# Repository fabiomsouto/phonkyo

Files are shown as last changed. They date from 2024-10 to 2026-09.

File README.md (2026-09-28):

# Phonkyo

A PiHat for Onkyo RI-enabled devices, hence the name (PiHat Onkyo).

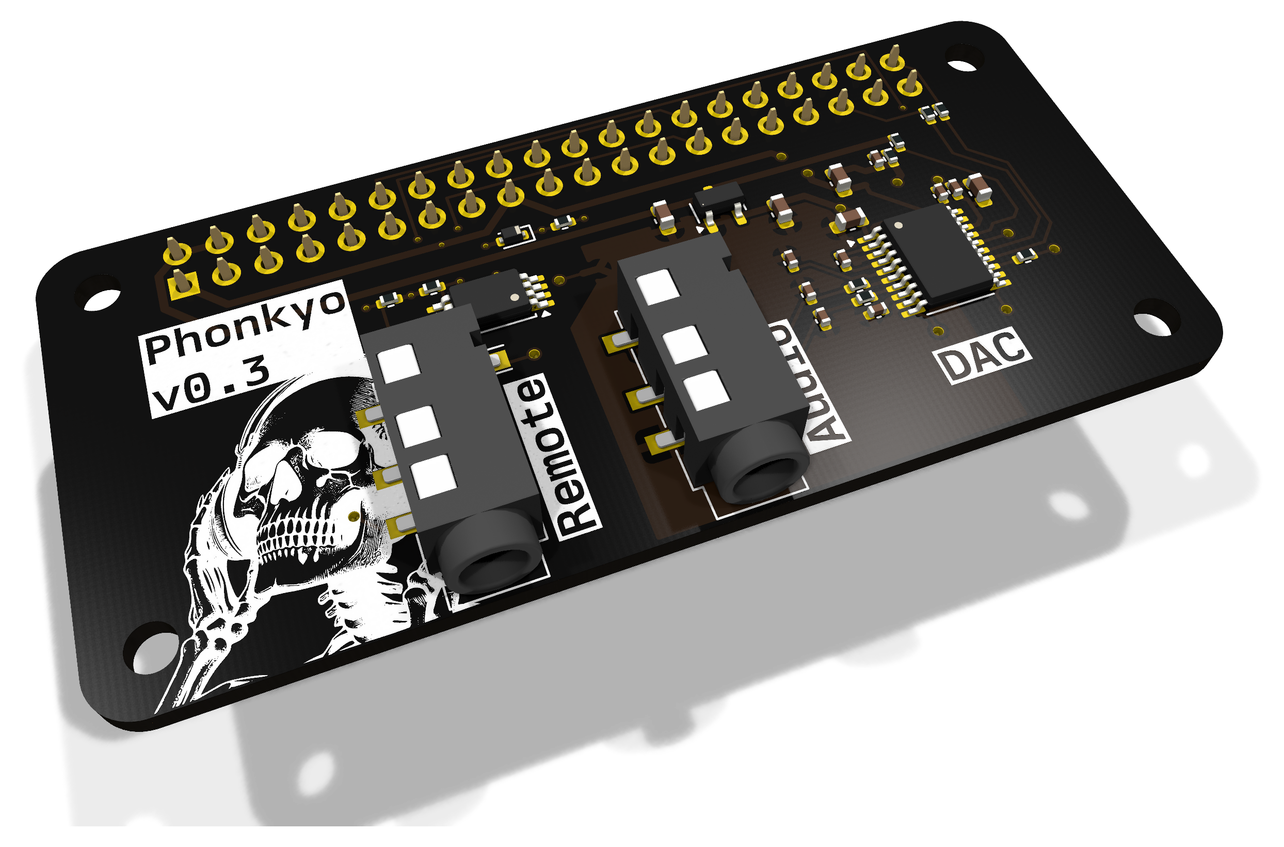
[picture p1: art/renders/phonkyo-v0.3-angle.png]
Phonkyo v0.3


Phonkyo makes a Raspberry Pi behave like one of Onkyo's own docks. Onkyo receivers have a small RI (Remote
Interactive) jack on the back, which docks use to switch the receiver on and change it to the dock input. Phonkyo speaks
the same protocol, so when you start playing music the receiver comes on and selects DOCK by itself, and after a few
minutes of silence it switches off again.

The music comes from the Pi itself: a PCM5102A DAC on the hat turns it into an AirPlay 2 receiver, a Spotify Connect
device and a headless Plexamp player, feeding the receiver's dock input through a line-level output.

I believe this device could also be used for other RI-enabled devices, such as Marantz, but I have no way to test it
(and therefore implement support)!

## What it does

- **Follows playback.** When something starts playing, the receiver powers on and switches to its DOCK input. When
  playback stops, it switches off again, but only if phonkyo was the one that turned it on.
- **High-quality line output.** PCM5102A DAC, 24-bit/192 kHz, on a 3.5 mm line-out jack meant for an amplifier's
  line input.
- **Onkyo RI control.** A second 3.5 mm jack connects to the receiver's RI port. It sends commands and listens to the
  codes the receiver sends back.
- **The receiver's remote controls Plexamp.** Play/pause, next, previous, fast-forward, rewind and repeat on the
  receiver's own remote work on Plexamp, just as they would on an Onkyo dock. AirPlay and Spotify can't be controlled
  this way; see `install/MANIFEST.md`.
- **Plug-and-play (v0.3).** A HAT ID EEPROM lets the Raspberry Pi recognise the board and load the sound card by itself,
  so there is nothing to add to `config.txt`.

Tested with an Onkyo TX-8020 and a Raspberry Pi Zero 2 W. Selecting the TV input and changing the volume are not
possible over RI on the TX-8020; `install/MANIFEST.md` records the full code search.

## Hardware

| | |
|---|---|
| Form factor | pHAT, 65 x 30 mm, for the Raspberry Pi Zero 2 W (fits any 40-pin Pi) |
| DAC | TI PCM5102A over I2S, own 3.3 V analog regulator |
| Outputs | 3.5 mm line out (J2), 3.5 mm Onkyo RI (J4) |
| RI line | GPIO25, with a series resistor and ESD clamp from v0.3 |
| ID EEPROM | CAT24C256 on ID_SD/ID_SC, write protect by solder jumper (v0.3) |

| Top | Bottom |
|---|---|
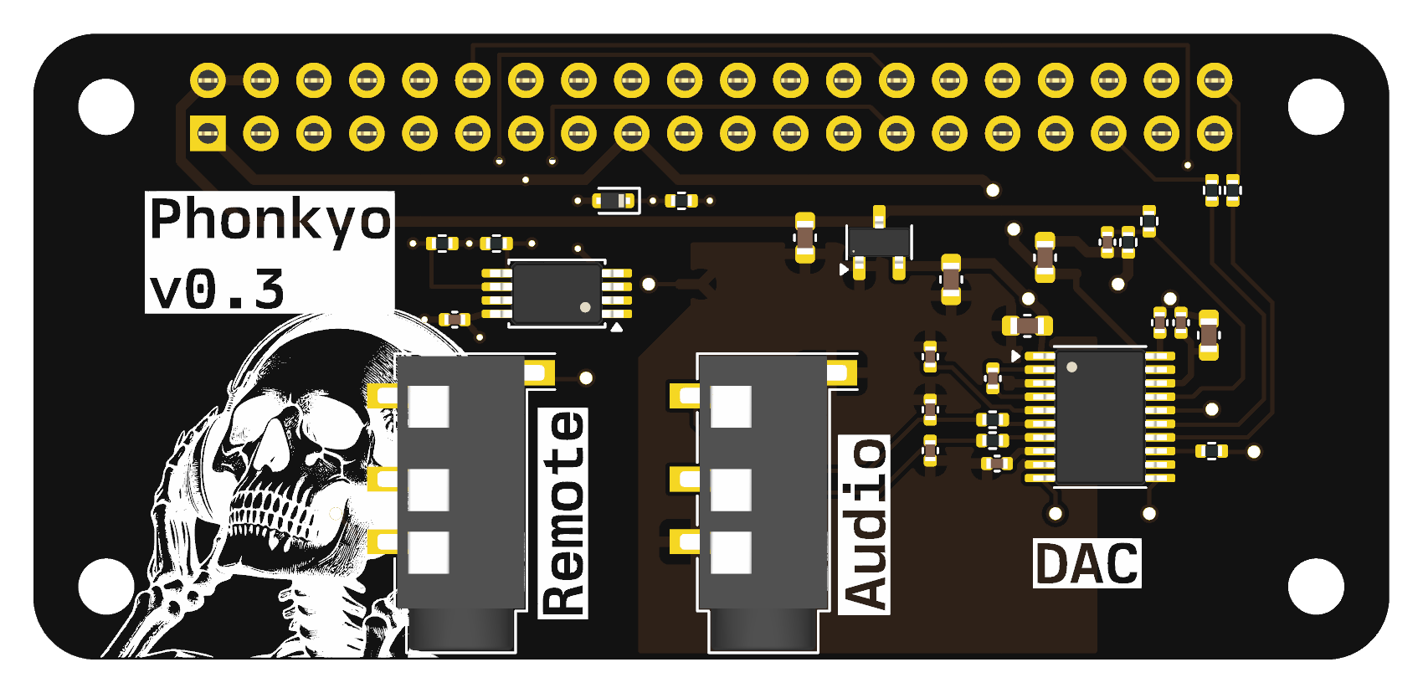
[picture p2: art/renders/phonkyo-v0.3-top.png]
Top
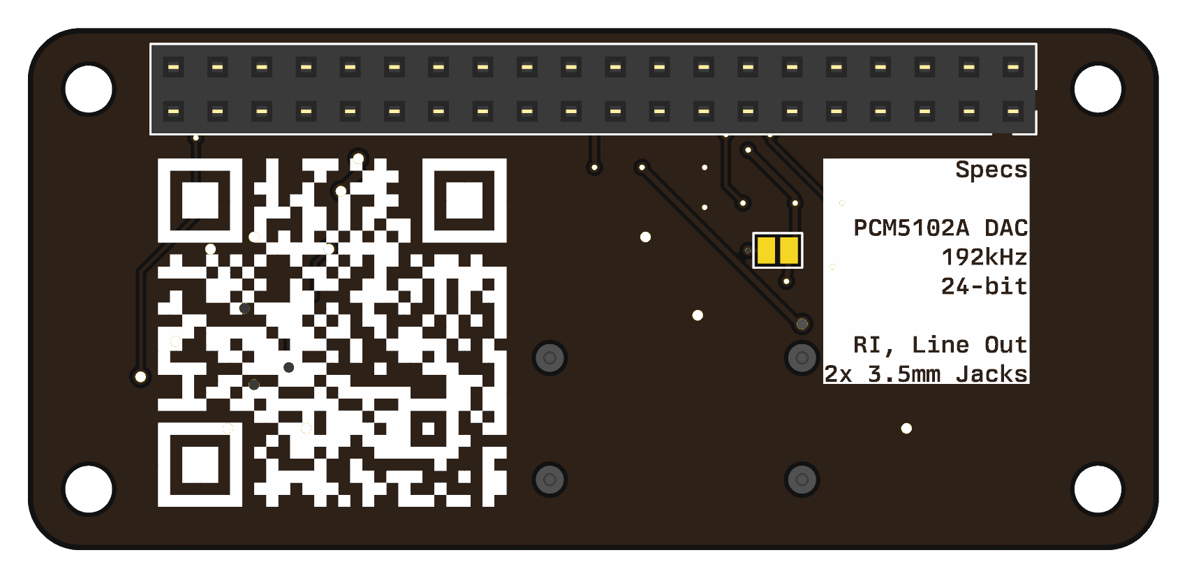
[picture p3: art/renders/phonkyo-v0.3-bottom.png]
Bottom
|  |  |

The design is in KiCad 10: `phonkyo.kicad_sch` and `phonkyo.kicad_pcb`. **v0.2 is the latest revision that has been built
and tested; v0.3 is designed but not yet built.**

## Buying one

Phonkyo is sold in small, hand-built batches through [obcecado.com/phonkyo](https://obcecado.com/phonkyo/).

- **Basic kit:** an assembled Phonkyo board with the 40-pin header already soldered. €30 plus shipping at the time
  of writing; the product page has the current price.
- **Complete kit:** also includes an audio cable, an RI cable and a 3D-printed case. Not available yet.
- **Shipping** is to European Union countries only.

To order, email [phonkyo@obcecado.com](mailto:phonkyo@obcecado.com?subject=Phonkyo%20order) with:

- the kit you want and how many
- the country it ships to
- your receiver model

I'll reply with the total including shipping and how to pay. There's no online checkout.

RI support varies from receiver to receiver, so check the
[compatibility table](https://obcecado.com/phonkyo/#receiver-compatibility) before ordering. Only the Onkyo TX-8020 has
been tested so far. If yours isn't listed, mention it in your email and I'll tell you what I know.

## Getting started

The software runs on Raspberry Pi OS Lite 64-bit (Trixie) on a Raspberry Pi Zero 2 W. On a fresh install, connect to
the Pi over SSH and run:

```sh
curl -fsSL https://obcecado.com/phonkyo/install.sh | bash
```

It asks which players you want and what to call the device, installs everything, and reboots when it's done. It takes
about 10-15 minutes. Plexamp needs a one-time sign-in code from [plex.tv/claim](https://plex.tv/claim), which it asks
for at the right moment. Running it again is safe, and is how you update. The script is `install/phonkyo-setup.sh`.

The [setup guide](https://obcecado.com/phonkyo/setup/) covers flashing the microSD card and the steps by hand, and
`install/MANIFEST.md` is the full technical record of what gets installed and why:

- the DAC and the ALSA setup
- AirPlay 2 (shairport-sync), Spotify Connect (raspotify) and Plexamp
- the RI control code in `software/phonkyo/` and the `phonkyo-monitor` service that follows playback

## Making boards

`production/v0.3/` has everything needed to order assembled boards from JLCPCB: Gerbers, drill files, and a BOM and
placement file with LCSC part numbers. Its README covers the order settings, the parts, and a bring-up checklist for new
boards. The 40-pin header is soldered by hand, and the ID EEPROM is programmed with `make flash` in `hardware/eeprom/`.

`docs/hardware-review-v0.3.md` is a design review of v0.3: what was found, and what was changed.

## Repository layout

| Path | Contents |
|---|---|
| `phonkyo.kicad_*` | KiCad 10 schematic, PCB and project |
| `production/` | Fabrication files for each revision |
| `hardware/eeprom/` | HAT ID EEPROM image source, device tree overlay, build and flash |
| `software/` | RI control, playback monitor, RI sniffer, board detection, systemd unit |
| `install/MANIFEST.md` | Software setup, measured RI timing and verified RI codes |
| `docs/` | Hardware review |
| `art/` | Board artwork and product renders |
| `3dmodels/` | 3D models missing from the KiCad library |
| `adc/` | PCM5102A datasheet |

## Release notes

### v0.1

Initial release of the Phonkyo project. There is no ID EEPROM present yet, and all the hat exposes is a 3.5mm jack that's
connected to the GPIO pin 25 on the Raspberry Pi. Use a mono or a stereo male-to-male cable to connect your Onkyo remote control to the hat.

### v0.2

This release adds the much acclaimed PCM5102A DAC to the design, allowing to expand the functionality of the device beyond a simple
remote control for your home theater system with RI. Depending on your needs, you will now be able to:
- Control your remote interface home theater to your liking
- Expose the Raspberry Pi as a Spotify device
- Expose the Raspberry Pi as an Airplay device
- Expose the Raspberry Pi as a Plex headless player

### v0.3

This release improves on the board design, particularly around power and ground rails, and removes the SCK jumper, as I don't
predict the need for an external clock source in this particular design. It also:
- Fits the HAT ID EEPROM, so the Raspberry Pi sets the board up by itself
- Adds ESD protection and a series resistor on the RI jack
- Moves the DAC's decoupling capacitors next to its pins, and adds one on the analog supply
- Moves the I2S bit clock onto the top layer, over an unbroken ground plane

## Related projects and documentation

[Macsbug article on PCM5102A](https://macsbug-wordpress-com.translate.goog/2021/02/19/web-radio-of-m5stack-pcm5102a-i2s-dac/)

[TI PCM5102A](https://www.ti.com/lit/ds/symlink/pcm5102a.pdf)

[phatDAC](https://shop.pimoroni.com/products/phat-dac) as inspiration

## License

Phonkyo is licensed under [Creative Commons Attribution-NonCommercial-ShareAlike 4.0 International](LICENSE)
(CC BY-NC-SA 4.0). You may build, modify and share it for non-commercial purposes, as long as you credit the project
and share your changes under the same licence. For commercial use, get in touch.

### Third-party content

These files are not covered by the licence above and remain the property of their owners:

- `adc/pcm5102a.pdf`: the PCM5102A datasheet, © Texas Instruments, included unaltered.
- `3dmodels/Jack_3.5mm_PJ-320D-4A.step`: the 3D model of the Korean Hroparts PJ-320D-4A jack (LCSC C95562), from
  LCSC/EasyEDA, used for the 3D renders only.
- Footprints and symbols from the KiCad libraries, used under the KiCad libraries' licence (CC BY-SA 4.0 with an
  exception for designs that use them).

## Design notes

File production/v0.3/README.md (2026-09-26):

# phonkyo v0.3 production files

Generated from `phonkyo.kicad_pcb` / `phonkyo.kicad_sch` with KiCad 10.

| File | Upload to JLCPCB as |
|---|---|
| `phonkyo-v0.3-gerbers.zip` (Gerbers + drills, not tracked in git) | Gerber file |
| `phonkyo-v0.3-bom-jlcpcb.csv` | BOM |
| `phonkyo-v0.3-cpl-jlcpcb.csv` | CPL / pick-and-place |

Rebuild the zip with:

```sh
cd production/v0.3 && zip phonkyo-v0.3-gerbers.zip *.g* *.drl
```

## Order settings

- 2 layers, 1.6 mm, 65 x 30 mm. ENIG is kinder to the two 0.65 mm-pitch
  TSSOPs; lead-free HASL also works.
- PCB Assembly on the **top side** for every SMD part.
- **J1 (40-pin female header) is not in the JLC BOM or CPL on purpose.**
  It is hand-soldered on the bottom side before each board is programmed.
  JLC does not ship loose parts with an assembly order, so buy the headers
  separately (see below).
- JP1 is a solder jumper, not a part. It ships **open**.

## Parts

LCSC numbers live in each symbol's `LCSC` field in the schematic, so the BOM
regenerates with them. Basic parts carry no loading fee. The 7 extended parts
each carry a one-off fee:

| Extended part | LCSC | Why this one |
|---|---|---|
| PCM5102APWR | C107671 | the DAC |
| CAT24C256YI-GT3 | C146734 | the ID EEPROM the design was checked against |
| PJ-320D-4A, Korean Hroparts | C95562 | matches the jack footprint |
| 2.2 nF 0402 C0G, Murata GRM1555C1H222JA01D | C385029 | C0G for the audio output filter; the basic 2.2 nF is X7R |
| 2.2 uF 0402 X5R 10 V, Samsung CL05A225KP5NSNC | C107369 | the basic 2.2 uF is only 6.3 V |
| 3.9 k 0402 1%, Yageo | C131467 | HAT spec pull-up value, no basic part exists |
| ESD5Z5.0T1G, onsemi, SOD-523 | C82044 | D1, ESD clamp on the RI jack; 5 V standoff so a 5 V receiver is not clipped. No basic ESD diode exists |

## Buy separately

| Part | LCSC | Notes |
|---|---|---|
| J1: 2x20 female header, 2.54 mm, 8.5 mm high, through-hole | C5124634 | one per board, hand-soldered; the usual pHAT height, so check it matches the v0.2 stack height |

The J1 reference stays in the schematic's `LCSC` field. If a JLC BOM is
regenerated from the schematic, delete the J1 line again.

## Before paying

In JLC's placement preview, check pin 1 of U1, U2 and U3, the cathode of D1
(it faces R12 and the via between them), and the orientation of J2/J4. KiCad and JLC often disagree on rotation for SOT-23 and TSSOP
footprints. Rotate them in their tool if needed.

## After the boards arrive

For each board:

1. Solder J1 on the bottom side.
2. Seat the board on a Pi with JP1 open.
3. Run `cd hardware/eeprom && make flash` on the Pi. It builds the image with a
   fresh UUID, writes it, reads it back and compares. The steps are in
   `install/MANIFEST.md`, section 10, on the software branch.
4. Bridge JP1 with solder to write-protect the EEPROM.

## Bring-up checklist for the first boards

1. **Visual:** D1's cathode faces R12. Pin 1 of U1, U2 and U3 is correct. No
   solder bridges on the two TSSOPs.
2. **Before fitting to a Pi,** with a multimeter: +5V, +3V3 and +3.3VA are not
   shorted to ground. GND to GNDA reads about 0 R (the NT1 net tie).
3. **Power:** on a Pi, U3's output (+3.3VA) is about 3.3 V.
4. **EEPROM:** solder J1, JP1 open, `make flash`, then reboot.
   `/proc/device-tree/hat/vendor` reads `obcecado.com`. To prove the overlay
   comes from the EEPROM, remove `dtoverlay=hifiberry-dac` from config.txt:
   the sound card should still appear in `aplay -l`. Then bridge JP1.
5. **Audio:** play through the amplifier and compare noise against v0.2.
6. **RI:** power-on and DOCK from the Pi (transmit through R12), and the sniffer
   (receive). If transmit fails, fit 0 R in place of R12.
7. **Optional:** measure the RI line's high level while the receiver sends, and
   the receiver's pull-down. With a pull-down of 10 k or more, R12 can go up to
   470 R to 1 k for more margin.

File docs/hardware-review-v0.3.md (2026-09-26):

# phonkyo v0.3 hardware review

**Date:** 2026-09-23, status updated 2026-09-26
**Design reviewed:** `phonkyo.kicad_sch` / `phonkyo.kicad_pcb` at commit `6e10180` ("add: revision 0.3"), KiCad 8 format
**Status reflects:** branch `feat/v0.3-caps-eeprom`, where the design is now in KiCad 10 format
**Board:** 2-layer, 65 x 30 mm pHAT for the Raspberry Pi Zero 2 W

## Scope and method

The review was done on commit `6e10180`. Placement, routing, zones, vias and
silkscreen were extracted with the KiCad API, and circuit findings were checked
against the PCM5102A datasheet (`adc/pcm5102a.pdf`, TI SLAS859C). Distances in
this document are pad edge to pad edge unless stated otherwise.

Each finding carries a **Status** line describing the design on
`feat/v0.3-caps-eeprom`. Measurements in the status lines come from that
branch.

On that branch, KiCad 10 DRC with schematic parity reports **0 unconnected
items, 0 parity errors and no DRC errors**. The only warnings are
library-mismatch warnings on older footprints. ERC reports no errors: the 4
missing `PWR_FLAG`s on +5V, +3V3, GND and GNDA have been added. Only label and
library-version warnings remain.

Only **v0.2** has been built. A v0.2 board was exercised end to end on a Pi Zero
2 W with an Onkyo TX-8020 receiver: DAC output on both channels, RI transmit, and
RI receive, with no audible noise. None of the findings below has been confirmed
or ruled out on fabricated v0.3 hardware, and no EMC measurements have been made.

## Summary

The analog design is sound. The analog/digital partition runs cleanly through
the DAC, the output filter is placed well, and the grounding follows a
deliberate single-point scheme. The issues found were in layout and product
readiness rather than circuit design:

| # | Finding | Status |
|---|---|---|
| 1 | Plot settings wrote to `production/v0.2` | **Fixed** |
| 2 | The I2S bit clock has the longest route and no reference plane | **Fixed**: B.Cu run cut from 54.8 to 15.1 mm |
| 3 | Decoupling capacitors far from their pins; none at AVDD | **Fixed** |
| 4 | XSMT | Withdrawn: leave as designed |
| 5 | Ground topology mixes split and unified approaches | **Decided**: keep the split; the single tie is now a net tie |
| 6 | ID EEPROM drawn but not fitted | **Fixed** |
| 7 | No ESD protection on the RI jack | **Fixed** |
| 8 | 470 R output resistors are poor for headphones | Closed: J2 is a line output for an amplifier |
| 9 | Logo silkscreen printed over the RI jack pads | **Fixed** |
| 10 | Pours touching NPTH holes and nearly reaching the board edge | **Fixed** |

## What is done well

- **The analog/digital split runs through U2 itself.** Analog pins 1 to 9
  (CPVDD, CAPP, CPGND, CAPM, VNEG, OUTL, OUTR, AVDD, AGND) sit at x = 148.3 mm,
  inside the GNDA pour. Digital pins 17 to 20 sit at x = 154.0 mm, outside it.
- **Single-point star ground.** One connection joins GNDA and GND: R11 (0 R) at
  review time, now the net tie NT1 (see finding 5).
- **Tight output filter.** R3 and R4 are 0.8 mm from OUTL and OUTR. The RC is
  470 R with 2.2 nF, giving a corner at about 154 kHz. The 2.2 nF capacitors are
  specified as C0G in the v0.3 BOM.
- **No DC-blocking capacitors on the outputs.** This is correct for the
  PCM5102A: its charge pump produces ground-centred outputs, and adding coupling
  capacitors here is a common mistake.
- **22 R series damping** on all three I2S lines (R7, R8, R9).
- **BCK avoids the analog region.** None of its route passes over the GNDA pour.
- **Ground stitching around the DAC.** 7 of the board's 13 GND vias sit around
  U2's digital side (x 149 to 156.5 mm), including one under the body for DGND
  pin 19. Of the rest, one is at the GND/GNDA tie point, two serve the ID
  EEPROM, one serves the RI ESD diode, and two are in the J4 area, one of them
  on the jack's sleeve.
- **XSMT power sensing.** R5/R6 divide +5V onto XSMT. This is TI's documented
  "External Power Sense Undervoltage Protection Mode" (datasheet §11.3,
  Fig. 39): the DAC mutes as the upstream rail falls, before the regulated
  3.3 V rails collapse. See finding 4 for why it should be left as it is.
- **SCK tied to GND.** This selects the internal PLL, which derives the system
  clock from BCK. That is correct for a slave-only PCM5102A driven by a Pi.
- **Mechanical.** The mounting holes are on the 58 x 23 mm Pi Zero pattern, and
  there is a keepout for the Pi's PoE header.

## Findings

Findings are ordered by value per effort, not by severity.

### 1. Plot output pointed at the v0.2 production folder

The v0.3 board's plot settings had `outputdirectory "production/v0.2"`, so
plotting v0.3 Gerbers would have written over the v0.2 fabrication files, which
are the ones that were actually manufactured. The repo also had no BOM or
position files for v0.3.

**Status: Fixed.** The plot output is now `production/v0.3`. That folder holds
the Gerbers (including F.Paste for the stencil), Excellon drills, a JLCPCB BOM
and CPL with LCSC part numbers kept in the schematic, and a README with the
order settings.

**Correction.** An earlier version of this review said the board had no
functional silkscreen and that the jacks were unlabelled. That was wrong. v0.2
and v0.3 both carry knockout labels: `Remote` by J4, `Audio` by J2, `DAC`, the
board name, and a specs block on the back. The earlier text-extraction step
missed them. Reference designators are hidden, which only matters for rework
and debugging. The jack mix-up during bring-up happened despite the labels.

### 2. The I2S bit clock has the worst route on the board

| | BCK | LRCK | DIN |
|---|---|---|---|
| Header to series resistor | 56.4 mm | 5.9 mm | 5.4 mm |
| Series resistor to U2 | 2.0 mm | 16.0 mm | 16.8 mm |
| **Total** | **58.4 mm** | 21.9 mm | 22.2 mm |

BCK has 54.8 mm on B.Cu, including a 32.8 mm straight run along the top edge at
y = 71.1, and 1.5 mm on F.Cu. GPIO18 (PCM_CLK) enters at header pin 12, at the
opposite end of J1 from the DAC. LRCK and DIN enter at pins 35 and 40, next to
the DAC. An earlier version of this finding compared BCK's header-to-resistor
length with the resistor-to-DAC length of LRCK and DIN; the totals above are
like for like.

B.Cu carries the GND pour, so the BCK trace cuts a 55 mm slot through it. F.Cu
has no pour outside the analog region, so for almost its whole length BCK has no
reference plane on either side. BCK runs at about 3.07 MHz and is driven with
fast Pi GPIO edges, so this trace is the most likely source of radiated emissions
on the board.

Timing is not a concern. The sub-nanosecond skew against LRCK and DIN is
negligible at these rates.

**Recommendation:** Route BCK on F.Cu. B.Cu stays continuous underneath it and
acts as its reference, and the slot goes away. If the route has to stay on B.Cu,
add a ground pour on F.Cu along its path.

**Status: Fixed.** The top-edge run is now on F.Cu, above the header at
y = 70.55, over an unbroken B.Cu ground. BCK drops through the header gap at
x = 155.3 to one via and takes the existing short B.Cu path to R9. Moving it
the rest of the way is not practical: the LRCK/DIN fan-out and the DVDD/LDOO
capacitors box it in near the DAC.

| | Before | Now |
|---|---|---|
| BCK on B.Cu | 54.8 mm | 15.1 mm |
| BCK on F.Cu | 3.5 mm | 45.2 mm |
| All B.Cu track | 102.5 mm | 64.1 mm |
| B.Cu GND pour | 1715 mm2 | 1734 mm2, still one piece |

To make room, ID_SCL now drops through the header gap east of pin 12, and the
EEPROM's +3V3 hop comes from a rail via at x = 123.6.

### 3. Decoupling capacitors were too far from the pins

At review time, C7 (100 nF, CPVDD pin 1) and C11 (100 nF, DVDD pin 20) sat 3.7
and 5.6 mm from their pins, and **AVDD (pin 8) had no local capacitor at all**.
It was fed from beside pin 1 through a B.Cu detour, about 9 mm from any
capacitor. The datasheet (§12.1) asks for supply and charge-pump decoupling "as
close as possible to the device". It gives no distance; about 2 mm is a common
rule of thumb. TI's reference layout decouples CPVDD and AVDD separately. On the
datasheet pinout, pin 1 is **CPVDD** and pin 8 is **AVDD**. The review
originally labelled pin 1 as AVDD.

**Status: Fixed.** The right-hand fan-out was reorganised: C11 and C12 moved to
0402, the LDOO loop around pins 19 and 20 was removed, and C14 (100 nF) was
added at AVDD. Distances now:

| Capacitor | Serves | Pad to pad |
|---|---|---|
| C7, 100 nF | CPVDD, pin 1 | **0.78 mm** |
| C14, 100 nF (new) | AVDD, pin 8 | **0.64 mm** |
| C11, 100 nF | DVDD, pin 20 | **0.64 mm** |
| C4, 2.2 uF | CAPP / CAPM, pins 2 / 4 | 1.23 / 1.24 mm |
| C12 / C13 | LDOO, pin 18 | 1.95 / 1.57 mm |
| C10, 2.2 uF | VNEG, pin 5 | 4.6 mm |
| C8, 10 uF | CPVDD / AVDD bulk | 5.0 mm to pin 1 |
| C9, 10 uF | DVDD bulk | 5.5 mm |

C10 is a reservoir on the charge-pump output, and C8/C9 are bulk capacitors.
All three are much less sensitive to a few mm of trace than the 100 nF parts,
so they were left in place.

### 4. XSMT: leave it as designed (finding withdrawn)

An earlier version of this review recommended increasing C6 to about 2.2 uF and
feeding the divider from +3V3. **Both would be mistakes**, and that
recommendation is withdrawn:

- The +5V divider implements TI's **External Power Sense Undervoltage
  Protection Mode** (datasheet §11.3, Fig. 39). If XSMT falls from high to low
  over 6 ms or more, the DAC treats it as an undervoltage event: soft mute starts
  at 2 V and analog mute at 1.2 V. Feeding the divider from +3V3 would defeat
  this.
- A large C6 would make XSMT lag the falling 5 V rail by about 15 ms, delaying
  the mute it exists to trigger. When XSMT is used as a digital control, §9.3.3
  also requires edges faster than 20 ns.
- The power-on pop concern does not hold up. The DAC holds its outputs muted
  until it sees valid I2S clocks, and the Pi does not start those until playback
  begins.

**One real limitation.** With a 2/3 ratio, soft mute begins only once 5 V has
fallen to about 3.0 V. That is already near the dropout of the regulators that
make the 3.3 V rails. On a Pi, 5 V also collapses within a few milliseconds when
power is pulled, so this mode offers limited protection whatever the ratio. A
normal shutdown mutes cleanly anyway, because the DAC mutes when the I2S clocks
stop. No change is recommended.

### 5. Ground topology

There are two pours:

- GNDA on F.Cu, covering only the analog region (x 129 to 151, y 80 to 100)
- GND on B.Cu, covering the whole board, **including beneath the analog region**

The two are joined at a single point. As a result, the analog circuitry sits
directly above the digital ground plane. The planes couple capacitively over
that whole area even though they share only one DC connection. The top layer
has no ground pour at all over the digital two-thirds of the board, which is
what leaves B.Cu signals such as BCK without a reference (see finding 2).

The design follows a coherent split-ground philosophy. TI's own guidance points
the other way, though: *"Most engineers use a shared common ground for an
entire device. GND can be considered AGND and DGND connected"* (§12.1). Many
general references agree, preferring a single unbroken plane with separation
achieved by placement and return-path control.

**Options considered:**

- **Unified:** one GND plane on B.Cu, a ground fill on F.Cu, and the analog
  section kept together by placement. This is the more common choice today.
- **Split:** keep the split, but make B.Cu beneath the analog region GNDA as
  well, so that the analog circuitry is not above digital ground.

**Status: Decided.** The pours stay as they are for v0.3, because the v0.2
prototype has no audible noise. The single tie, R11 (0 R), is replaced by the
net tie **NT1**: a copper bridge in the same place, with no part to place. A
ferrite bead there was considered and rejected. It would put impedance in the
return path of the I2S lines that cross between the two grounds. Revisit the
unified approach if v0.3 shows noise or fails EMC.

### 6. The ID EEPROM was drawn but not fitted

At review time, U1 (CAT24C256), JP1 (write protect), R1/R2 (3.9 k pull-ups) and
C1 were in the schematic but had no footprints and were not on the PCB. Without
the EEPROM the board is not HAT-spec compliant. The Pi cannot identify it or
apply its overlay automatically, so every user has to edit `config.txt` by hand.

**Status: Fixed.** All five are fitted on ID_SD and ID_SC (GPIO0/1, header pins
27/28), with U1 at address 0x50:

- U1 is a TSSOP-8 in the strip above the jacks. Both ID lines run on F.Cu, and
  B.Cu is used only for short hops under the power rails.
- JP1 is a solder jumper on the bottom side, made of copper pads with no part.
  Boards ship with it open so the EEPROM can be programmed; bridge it afterwards
  to write-protect.
- The image in `hardware/eeprom/` is a 906-byte HAT v1 image with vendor
  `obcecado.com`, `product_id` 0x0001 and `product_ver` 0x0003. It embeds the
  sound-card overlay and the GPIO settings. GPIO0/1 are deliberately absent from
  its GPIO map, because the spec reserves them.
- Program it with `make flash` on a Pi, with JP1 open. It rebuilds the image
  so each board gets its own UUID, writes it, and reads it back to compare.
  `eepflash.sh` brings up the I2C bus on GPIO0/1 itself.

### 7. No ESD or series protection on the RI jack

J4's tip connects directly to GPIO25. J4 is a user-accessible connector, so an
electrostatic discharge into the jack goes straight to a SoC pin.

On a TX-8020 the RI line idles low and has no pull-up, so it presents no DC
hazard. It reads low even against the Pi's internal pull-up. Other receiver
models have not been checked.

**Recommendation:** Add a low-capacitance ESD diode to GND at J4, and a series
resistor between J4 and GPIO25. The receiver holds the line low through an
unknown impedance, and a series resistor forms a divider with it. Measure the
receiver-side pull-down before choosing a value, so that a logic high still
reaches the receiver at a valid level.

**Status: Fixed.** J4's tip now reaches GPIO25 through R12 (100 R), and D1
(onsemi ESD5Z5.0T1G, SOD-523) clamps the jack side to GND. The 5 V standoff
means a receiver that drives 5 V is not clipped. 100 R was chosen because the
receiver's pull-down is still unmeasured: it keeps the transmit level safe
while limiting current into the GPIO, compared with the direct connection on
v0.2. If the pull-down is later measured at 10 k or more, raising R12 to
470 R to 1 k would add margin. The parts sit on F.Cu between the +3V3 and +5V
rails, where GPIO25 crosses on B.Cu. The skull logo and the jack body leave no
room next to J4 itself.

### 8. Output impedance

The 470 R series resistors are fine for driving a line input (10 k and above).
With 32 R headphones, though, the attenuation is about 24 dB. People will plug
headphones into a 3.5 mm jack.

**Recommendation:** Make it clear that J2 is a line output; its silkscreen
currently reads `Audio`. If driving headphones matters, reduce the series
resistance and rescale the filter capacitor to keep the corner frequency.

**Status: Closed.** phonkyo is meant to feed an amplifier's line input, not
headphones. Into 10 k or more, 470 R costs about 0.4 dB.

### 9. Logo silkscreen was printed over the RI jack pads

Found after the review. The skull logo's silkscreen covered 60 to 89% of J4's
solder pads (T, R1 and R2). The plot settings did not subtract the solder mask
from the silkscreen, so the silkscreen Gerber printed ink onto those pads,
risking poor solder joints on the RI jack. The project's DRC has
`silk_over_copper` set to ignore, which is why DRC did not report it.

**Status: Fixed.** The plot settings now subtract the mask from the silkscreen,
so the silkscreen is clipped at every pad opening. The logo is unchanged
elsewhere. A related case came up with the new ESD diode: D1's SOD-523 outline
put its cathode bar on the ring of the adjacent via. D1 was moved 0.3 mm so
the bar sits in clear board. KiCad's 3D viewer still draws the overlap unless its own "clip
silkscreen at solder mask edges" option is turned on; the Gerbers are what
count.

### 10. Copper pours touched the NPTH holes and nearly reached the board edge

Found in a pre-order check. A DRC with the project's ignored checks switched on
and JLC-style limits showed the GND and GNDA pours touching all 10 NPTH holes:
the 4 mounting holes and the jacks' locating pegs, at 0.0005 mm. They also
came within 0.05 mm of the board edge. The project allowed 0 mm hole clearance
and 0.05 mm edge clearance. Copper at an NPTH hole is drilled through, which
risks burrs, and at the mounting holes the metal standoffs sit on it. Copper
at the edge can be exposed when the outline is routed.

**Status: Fixed.** The project now requires 0.25 mm from holes and 0.3 mm from
the edge, and the pours were refilled. No tracks moved. The B.Cu GND pour is
still one piece, at 1673 mm2 (down from 1734). The strict DRC now reports only
artwork items that v0.2 was built with: the logos have no courtyard, the logo
overlaps J4's outline, the TrueType labels are thinner than the check likes,
and silkscreen crosses pads (clipped at plot time, see finding 9).

## Remaining for v0.4

1. Measure the receiver's RI pull-down, and raise R12 if it allows
   (finding 7).
2. Revisit the ground topology only if v0.3 shows noise or fails EMC
   (finding 5).
3. Optionally relabel J2 `Line Out` (finding 8).

## Related

- `install/MANIFEST.md`: the software stack, measured RI timing, and verified RI
  codes
- `hardware/eeprom/`: the HAT ID EEPROM image and its build
- `production/v0.3/README.md` (on `feat/v0.3-caps-eeprom`): order settings,
  parts and EEPROM programming for the first v0.3 batch

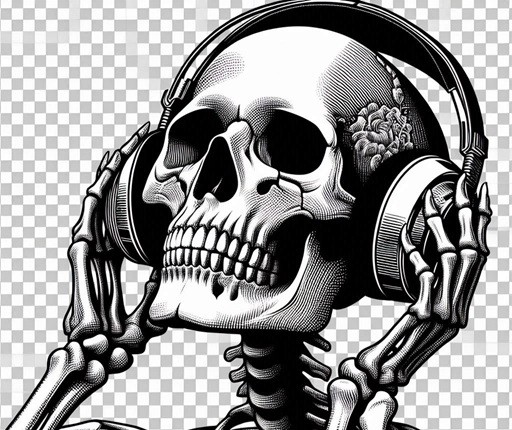
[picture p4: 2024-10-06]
art/skeleton.jpg

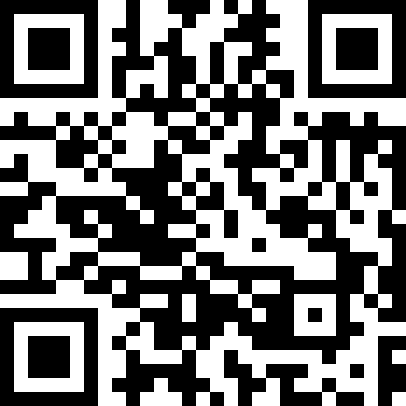
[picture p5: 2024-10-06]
art/obcecado.png

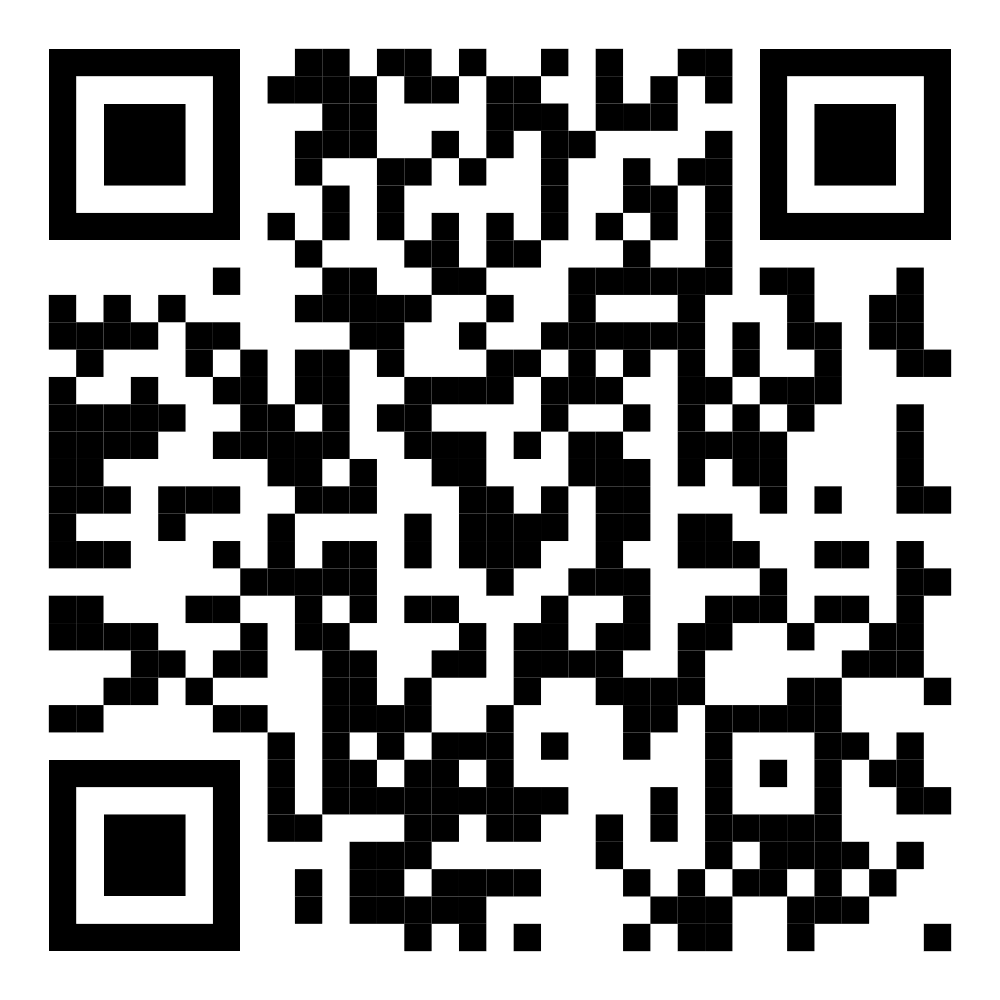
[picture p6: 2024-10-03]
art/phonkyo-qr-v0-1.png

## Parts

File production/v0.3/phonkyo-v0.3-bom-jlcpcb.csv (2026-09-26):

Comment | Designator | Footprint | LCSC Part #
100n | C1 | C_0402_1005Metric | C1525
2.2n | C2,C3,C6 | C_0402_1005Metric | C385029
2.2u | C4,C10 | C_0402_1005Metric | C107369
1u | C5 | C_0603_1608Metric | C15849
0.1u | C7 | C_0603_1608Metric | C14663
10uf | C8,C9,C13 | C_0603_1608Metric | C19702
0.1u | C11,C12,C14 | C_0402_1005Metric | C1525
ESD5Z5.0 | D1 | D_SOD-523 | C82044
LineOutJack | J2 | Jack_3.5mm_KoreanHropartsElec_PJ-320D-4A_Horizontal | C95562
RIJack | J4 | Jack_3.5mm_KoreanHropartsElec_PJ-320D-4A_Horizontal | C95562
3.9k | R1,R2 | R_0402_1005Metric | C131467
470 | R3,R4 | R_0402_1005Metric | C25117
10k | R5 | R_0402_1005Metric | C25744
20k | R6 | R_0402_1005Metric | C25765
22 | R7,R8,R9 | R_0402_1005Metric | C25092
100 | R12 | R_0402_1005Metric | C25076
CAT24C256 | U1 | TSSOP-8_4.4x3mm_P0.65mm | C146734
PCM5102A | U2 | TSSOP-20_4.4x6.5mm_P0.65mm | C107671
XC6206P332MR | U3 | SOT-23-3 | C5446

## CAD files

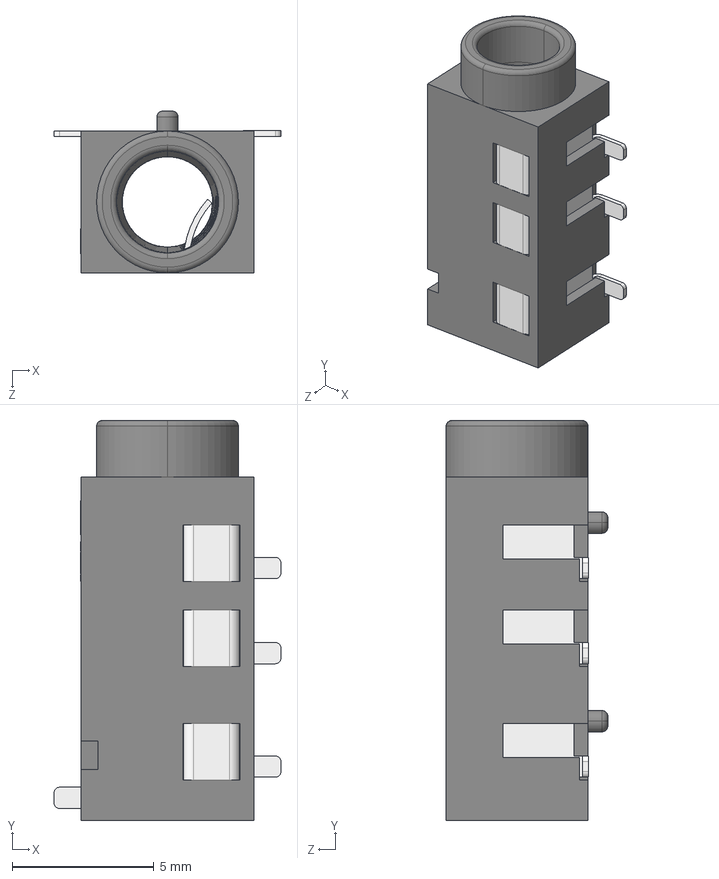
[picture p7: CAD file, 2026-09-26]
3dmodels/Jack_3.5mm_PJ-320D-4A.step
8.00 x 14.1 x 5.70 mm

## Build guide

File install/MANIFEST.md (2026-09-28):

# Phonkyo software manifest

Everything the phonkyo software stack needs on top of a stock OS image, and
why. `install/phonkyo-setup.sh` automates it:

```sh
curl -fsSL https://obcecado.com/phonkyo/install.sh | bash
```

The site serves a copy of `install/phonkyo-setup.sh`. The installer pins the
phonkyo release it installs (`PHONKYO_REF`, a `sw-v*` tag), the nqptp and
shairport-sync commits, and the Plexamp version. It was verified on
2026-09-28 on a freshly flashed Raspberry Pi OS Lite 64-bit (Trixie) card on a
Zero 2 W with a v0.2 board: all five services came up and the DAC became
card 0 after its reboot. When a step here changes, change the installer too.

## Target platform

| | |
|---|---|
| Board | Raspberry Pi Zero 2 W (BCM2710A1, ARMv8) |
| HAT | phonkyo v0.2 (PCM5102A DAC + RI jack), the hardware everything here was verified on. v0.3 adds the ID EEPROM and RI protection and has not been built yet |
| OS | Raspberry Pi OS **Lite 64-bit**, Trixie (Debian 13) |
| Verified image | `2026-09-15-raspios-trixie-arm64-lite.img.xz` |
| Kernel at time of writing | `6.18.50+rpt-rpi-v8` |

> The 64-bit image requires a Zero 2 W. The original Zero / Zero W (BCM2835,
> ARMv6) cannot boot it — no `kernel.img`, no `bcm2835-*.dtb`.

## 1. First-boot provisioning

Trixie uses **cloud-init**, *not* `custom.toml` (that was Bookworm and is
silently ignored on Trixie). Seed files go on the boot partition, which
cloud-init reads via `seedfrom: file:///boot/firmware`:

- `user-data` — hostname, user, SSH keys, `ssh_pwauth: false`
- `network-config` — netplan v2: wlan0 + usb0
- `meta-data` — `instance_id` (change it to force re-provisioning)

`/boot/firmware/ssh` (empty file) makes `sshswitch.service` enable
`ssh.service`, which is **not** enabled by default on Lite.

## 2. Boot configuration — `/boot/firmware/config.txt`

```ini
#dtparam=audio=on                 # onboard audio off; the PCM5102A is the output
dtoverlay=vc4-kms-v3d,noaudio     # HDMI audio off, so the DAC is card 0

[all]
dtoverlay=dwc2                    # USB ethernet gadget (SSH fallback)
dtoverlay=hifiberry-dac           # PCM5102A via I2S
```

`/boot/firmware/cmdline.txt` gains `modules-load=dwc2,g_ether` after `rootwait`.

The PCM5102A needs no I2C control, so `hifiberry-dac` is the correct overlay
and registers unconditionally — the card appears even with no HAT attached.

## 3. Packages from Debian/RPi repos

```
alsa-utils avahi-daemon          # present on Lite already
python3-lgpio gpiod python3-gpiozero
```

**`pigpiod` is gone from Trixie.** Only client-side remnants survive
(`python3-pigpio`, `pigpio-tools`, `libpigpiod-if*`, one tagged "deprecated")
and there is no daemon for them to talk to. RI control uses **lgpio** instead —
same author as pigpio, its designated successor, and supported on Pi 5.

## 4. Spotify Connect — raspotify

Third-party apt repo:

```sh
curl -sSL https://dtcooper.github.io/raspotify/key.asc \
  | sudo tee /usr/share/keyrings/raspotify_key.asc >/dev/null
echo "deb [signed-by=/usr/share/keyrings/raspotify_key.asc] https://dtcooper.github.io/raspotify raspotify main" \
  | sudo tee /etc/apt/sources.list.d/raspotify.list >/dev/null
sudo apt-get update && sudo apt-get install -y raspotify
```

Installed version: `0.48.2~librespot.v0.8.0-9c7d756`. Enables itself at boot.
Stock `/etc/raspotify/conf` works as-is — card 0 is the DAC.

## 5. AirPlay 2 — nqptp + shairport-sync (from source)

Debian ships `shairport-sync 4.3.7` but **AirPlay 1 only**, and `nqptp`
is not packaged at all. AirPlay 2 requires both.

Build dependencies:

```
build-essential git autoconf automake libtool
libpopt-dev libconfig-dev libasound2-dev
avahi-daemon libavahi-client-dev libssl-dev libsoxr-dev
libplist-dev libplist-utils libsodium-dev
libavutil-dev libavcodec-dev libavformat-dev
uuid-dev libgcrypt-dev xxd
libglib2.0-dev          # for the D-Bus/MPRIS interfaces
systemd-dev             # for --with-systemd-startup
```

> `plistutil` is in **`libplist-utils`**, not `libplist-dev`. Omitting it
> fails at `./configure`, not at compile time.

```sh
git clone --depth 1 https://github.com/mikebrady/nqptp.git
cd nqptp && autoreconf -fi && ./configure --with-systemd-startup && make -j2 && sudo make install

git clone --depth 1 https://github.com/mikebrady/shairport-sync.git
cd shairport-sync && autoreconf -fi && ./configure \
    --sysconfdir=/etc --with-alsa --with-soxr --with-avahi \
    --with-ssl=openssl --with-airplay-2 \
    --with-dbus-interface --with-mpris-interface --with-systemd-startup \
  && make -j2 && sudo make install
```

**`--with-systemd-startup` is required.** Without it `make install` installs
neither the service unit (`/usr/local/lib/systemd/system/`) nor the
`shairport-sync` user, and `systemctl enable shairport-sync` fails. It needs
`systemd-dev` for pkg-config's systemd data, which a fresh Lite image lacks.
An earlier version of this manifest passed `--with-systemd`, which configure
ignores as unrecognised; the first test of the installer on a fresh card
exposed both. Compiling takes a few minutes on a Zero 2 W.

The D-Bus and MPRIS interfaces register `org.gnome.ShairportSync` and
`org.mpris.MediaPlayer2.ShairportSync` on the system bus. `make install` adds
their policy files to `/etc/dbus-1/system.d/`; the default policy lets any
local user call them. They report whether a session is active, the player
state, the sender's name and the current track's metadata.

**Remote control does not work in AirPlay 2 mode.** Verified on 2026-09-28
with an iPhone, from both the Spotify app and Apple's Podcasts app:
`RemoteControl.Available` stays `false`, `Next`/`PlayPause` through either
interface have no effect, and `RemoteCommand` returns status 490 (no
remote-control channel from the sender). shairport-sync's remote control uses DACP, which senders only offer
in classic AirPlay sessions; AirPlay 2 senders are controlled over a newer
protocol that shairport-sync does not implement. So the receiver's transport
buttons cannot drive AirPlay playback. The interfaces are still worth
building for the state and metadata.

Zero 2 W has 512 MB RAM — use `-j2`, not `-j4`.

`/etc/shairport-sync.conf` needs two edits from stock:

```
name = "phonkyo";
output_device = "hw:CARD=sndrpihifiberry";
```

Address the DAC by card **name**, never `hw:0` -- see section 10. raspotify and
Plexamp use the ALSA default and need no change while the DAC is the only card.

## 6. Plexamp headless

Needs `nodejs` (Debian Trixie ships 20.19.2, which satisfies it).

```sh
sudo apt-get install -y nodejs
curl -sSL -o /tmp/plexamp.tar.bz2 \
  https://plexamp.plex.tv/headless/Plexamp-Linux-headless-v4.13.2.tar.bz2
sudo tar -xjf /tmp/plexamp.tar.bz2 -C /opt
sudo chown -R "$USER":"$USER" /opt/plexamp
```

### The claim step resists scripting

First run is **interactive and the token is single-use** — it is consumed the
moment it is submitted. A script that supplies the token but fails at the
*second* prompt (player name) still burns the token and writes no config.

Neither a plain pipe nor `ssh -tt` works: the first needs a TTY the prompts
never get, the second echoes both lines into the *first* prompt before the
second appears. Use `expect`, which waits for each prompt:

```expect
#!/usr/bin/expect -f
set timeout 180
spawn node js/index.js
expect -re "claim token:"        ; send -- "[lindex $argv 0]\r"
expect -re "name \\(e.g."        ; send -- "[lindex $argv 1]\r"
expect -re "signed in and ready"
sleep 20
```

Settings land in `~/.local/share/Plexamp/Settings/`.

### systemd unit

The shipped `/opt/plexamp/plexamp.service` hardcodes `User=pi` and
`/home/pi/plexamp`. Rewrite for the real user and install path; Plexamp reads
its settings from the service user's `~/.local/share/Plexamp`.

## 7. Diagnostics tooling

`avahi-utils` is **not** on the Lite image. Without it `avahi-browse` does not
exist, and its absence is indistinguishable from "no services are advertising".
Install it before debugging any mDNS/AirPlay discovery problem.

## 8. Nice to have

- `log2ram` (**optional**) — was on the original install, to cut SD card writes.
  It adds little on this image. Raspberry Pi OS already keeps the journal in
  RAM: `/usr/lib/systemd/journald.conf.d/40-rpi-volatile-storage.conf` sets
  `Storage=volatile`, `/var/log/journal` stays empty, and there is no rsyslog.
  Measured on 2026-09-28 after about two days of uptime: `/var/log` held
  892 KB, and the only writes were apt/dpkg logs from package installs.
  Worth adding only if something starts logging to files under `/var/log`.
- Persistent logs would need `Storage=persistent` in
  `/etc/systemd/journald.conf.d/`; weigh that against flash wear. The installer
  should leave the journal volatile.

## Status

- [x] Boot config / DAC overlay — verified, tone out both channels
- [x] python3-lgpio
- [x] raspotify
- [x] nqptp
- [x] nqptp + shairport-sync with AirPlay 2 — `01078ad-AirPlay2-smi10-OpenSSL-Avahi-ALSA-soxr-metadata-dbus-mpris`
- [x] Plexamp 4.13.2 claimed as `phonkyo`, systemd unit rewritten
- [x] avahi-utils
- [x] **RI control on GPIO25 via lgpio** — verified end to end on a real receiver
- [x] `phonkyo-monitor` playback-follow service
- [x] Receiver remote controls Plexamp (play/pause, skip, seek, repeat) — verified with a TX-8020 remote
- [x] `phonkyo-setup.sh` installer — verified on a freshly flashed card
- [ ] log2ram (optional; see section 8)

## 9. RI control timing (measured, Pi Zero 2 W)

`pigpio` is the wrong tool here for two independent reasons: it is no longer
packaged on Trixie, **and** its DMA timebase defaults to the PCM peripheral —
the same block the I2S DAC drives (`pigpiod -t 0` switches it to PWM, but that
is a footgun to ship). `lgpio` goes through `/dev/gpiochip0` and touches
neither PCM nor PWM, so there is no contention with the DAC.

The cost is software-generated timing. Measured worst-case error on a 1000 us
pulse, 400 samples per cell:

| Load | normal scheduling | SCHED_FIFO prio 50 |
|---|---|---|
| I2S idle | +12.1 us | +11.5 us |
| I2S streaming | +57.9 us | +48.2 us |
| I2S + 4 saturated cores | **+4005 us** | **+2.5 us** |

**`SCHED_FIFO` is mandatory, not an optimisation.** Under CPU contention,
ordinary scheduling produces 4 ms errors against a 1-2 ms bit period — every
frame corrupt. With real-time priority the same load costs 2.5 us.

I2S activity alone is not a problem: ~48 us worst case is under 5% of a bit
period, against roughly 20% receiver tolerance.

One `lgpio.gpio_write` costs ~6.8 us, so the transmitter uses absolute
deadlines rather than relative sleeps to stop that accumulating across a frame.
Measured end-to-end: 3.43 us worst-case edge error over 270 edges.

Installer implication: the RI service needs `CAP_SYS_NICE` (or root), e.g.
`AmbientCapabilities=CAP_SYS_NICE` in its unit.

### Verified and open

- **Protocol constants** (3000/1000/1000/2000 us, 12 bits) came from community
  reverse-engineering and are now confirmed on a TX-8020 in both directions:
  the receiver acts on frames sent with them, and frames it sends decode with
  them, with captured pulses within about 25 us of nominal.
- **Command codes** are mapped in both directions; see "Verified RI command
  codes" and "Codes the receiver sends *to* the dock" below.
- **RI electrical levels (open).** On a TX-8020 the line idles low. The level the
  receiver drives when it sends has not been measured; some sources describe
  5 V. On v0.2, GPIO25 connects to the J4 tip directly. From v0.3 it goes
  through R12 (100 R), with D1 (5 V ESD clamp) on the jack side, which limits
  the current into the GPIO if a receiver does drive 5 V.

## 10. HAT ID EEPROM -- automating setup for buyers

Source in `hardware/eeprom/`. Fitted from v0.3 (U1, R1, R2, C1, JP1); v0.2
has none. It is what turns "edit config.txt by hand" into "flash the image,
plug in the HAT, boot".

### What the firmware does with it

At boot the Pi reads the EEPROM at 0x50 on ID_SD/ID_SC (GPIO0/1) and:

1. **applies the embedded device tree overlay** -- the PCM5102A sound card
   is instantiated with no `dtoverlay=` line in config.txt at all
2. **applies the GPIO function/pull settings** declared in the EEPROM
3. **publishes identity** under `/proc/device-tree/hat/` -- vendor, product,
   product_id, product_ver, uuid

### Build

```sh
cd hardware/eeprom && make          # -> phonkyo.eep
make verify                          # dump it back and eyeball the fields
make flash                           # on the Pi, HAT fitted, JP1 open
```

The image identifies the board as vendor `obcecado.com`, product
`phonkyo DAC + Onkyo RI`, `product_id` 0x0001, `product_ver` 0x0003.

### Programming a board

1. Solder J1 (boards ship without it) and seat the board on a Pi.
2. Leave JP1 open, so WP floats low and the EEPROM is writable.
3. `make flash`. It rebuilds the image (so the board gets its own UUID),
   writes it, reads the chip back, compares the bytes, and prints the UUID.
   `eepflash.sh` brings up an I2C bus on GPIO0/1 by itself; nothing needs
   adding to config.txt.
4. Bridge JP1 with solder to write-protect the EEPROM.
5. Reboot. `/proc/device-tree/hat/` should now exist, and
   `python3 -m phonkyo.hat` should report the board.

**`eepmake` must be run with `-v1`.** It now defaults to the HAT+ format
(Pi 5 era), which dropped `gpio_drive`/`gpio_slew`/`gpio_hysteresis` and is
not what Zero 2 W firmware expects. Without it the build dies with
`'gpio_drive' not supported on HAT+`. The Makefile handles this.

Tooling is already present on the Trixie image via `rpi-eeprom`: `eepmake`,
`eepflash.sh`, `eepdump`, plus `dtc` from `device-tree-compiler`.

Verified: builds to a 906-byte image with the 778-byte overlay embedded, and
every field round-trips through `eepdump`.

`product_uuid` is left as zeros in the settings file, so `eepmake` generates a
new UUID every time it builds the image. `make flash` therefore rebuilds before
every write. Do not program a batch from one prebuilt `phonkyo.eep` with
`eepflash.sh` directly, or every board will share one UUID. Bump `product_ver`
per board revision so software can adapt.

### What software does with it

`software/phonkyo/hat.py` reads the identity and degrades gracefully -- on a
board with no EEPROM (v0.2, or a v0.3 not yet programmed) `detect()` returns
`None` and callers keep their current behaviour.

### Do not hardcode `hw:0`

Card numbering is not stable across machines. A buyer who leaves HDMI audio
enabled gets the DAC on card 1, and a hardcoded `hw:0` then plays into the
television. `hat.alsa_card()` resolves the card by *name*
(`hw:CARD=sndrpihifiberry`), which removes that whole class of support
ticket.

## 11. Playback-follow service (phonkyo-monitor)

Watches the DAC and drives the amp over RI: power on + select DOCK when audio
starts, power off after an idle timeout. It also listens for the receiver's
transport buttons and passes them to Plexamp (see "The receiver's remote"
below). `--remote control|log|off` sets whether it acts on them, only logs
them, or ignores them; the default is `control`.

### Detecting playback

Do **not** key on `subdevices_avail` in `/proc/asound/.../info` ("is the device
claimed"). Plexamp opens the PCM at startup and holds it in `PREPARED` state
indefinitely while idle, so that test reads as permanent playback and the amp
never switches off. The previous phonkyo build had this bug.

Require `state: RUNNING` **and** `hw_ptr` advancing between polls. That
separates real playback from a device that is merely open, or open and stalled.

### Only switch off what you switched on

Track power state starting at `False`, so the service never sends `power_off`
for an amp it did not power up. Otherwise switching the receiver on yourself
for vinyl or TV gets it silently killed after the idle timeout.

### systemd gotchas

- **`CAP_SYS_NICE` is required** for `SCHED_FIFO`. Without it the transmitter
  refuses to send rather than emit frames it cannot time reliably.
- **lgpio needs a writable working directory.** It creates `.lgd-nfy*`
  notification FIFOs in the CWD; under `ProtectSystem=strict` a `/opt` working
  directory is read-only and the module fails at *import* with
  `FileNotFoundError: '.lgd-nfy-3'`. Use `RuntimeDirectory=phonkyo` plus
  `WorkingDirectory=/run/phonkyo`.
- Service user needs supplementary groups `gpio` (for `/dev/gpiochip0`) and
  `audio`.

### The receiver's remote

With DOCK selected, the receiver forwards its remote's transport buttons to the
dock over RI. `phonkyo/remote.py` listens for them inside `phonkyo-monitor`.
The listener lives in the monitor because RI is one wire used in both
directions: one object (`RILine`) owns the GPIO, listens by default, and pauses
listening while it transmits. A separate listener process would hold the GPIO
and make every `power_on_dock` fail with the line busy.

Each press arrives as 3 frames about 50 ms apart and is folded into one press.
Fast-forward and rewind keep firing every 0.4 s while held.

| Button | Code | Action (Plexamp) |
|---|---|---|
| Play/pause | `0x5CB` | `playPause` |
| Next track | `0x5C8` | `skipNext` |
| Previous track | `0x5C9` | `skipPrevious` |
| Fast-forward | `0x5C0` | `seekTo` current + 10 s |
| Rewind | `0x5C1` | `seekTo` current - 10 s |
| Repeat | `0x5D3` | `setParameters repeat`, cycling off -> all -> one -> off |
| Shuffle | `0x5D2` | none: `setParameters shuffle` is accepted but ignored |
| Menu | `0x5D6` | none: deliberately unassigned |

Verified on 2026-09-28 with a TX-8020 remote and Plexamp 4.13.2. Plexamp's
local API is on `127.0.0.1:32500`. It lists `stepForward`/`stepBack` as
controllable but answers 404, hence `seekTo`.

Presses only reach Plexamp when Plexamp is the player: the listener reads which
process owns the DAC (`owner_pid` in the PCM status, resolved to its process
through `Tgid`, since ALSA records the opening thread, e.g. Plexamp's
`libuv-worker`), and ignores presses while shairport-sync or librespot is
playing. AirPlay 2 senders offer no remote-control channel (section 5), and
librespot has no local control interface; the Spotify Web API would be the way
in, and is not set up.

### Verified RI command codes

Recovered from the previous working install and confirmed against hardware:

| Code | Action |
|---|---|
| `0x17F` | power on **and** select DOCK |
| `0x170` | select DOCK |
| `0x420` | power off |
| `0x2B0/1/2` | dimmer high / mid / low |

### Codes the receiver sends *to* the dock

RI is bidirectional. With DOCK selected, the receiver forwards its transport
buttons to the attached dock. Captured from a real receiver, three isolated
frames each:

| Code | Action |
|---|---|
| `0x5C0` | fast-forward |
| `0x5C1` | rewind |
| `0x5C8` | track forward |
| `0x5C9` | track back |
| `0x5CB` | play/pause |
| `0x5D2` | shuffle |
| `0x5D3` | repeat |
| `0x5D6` | menu |

All are in the `0x5C_`/`0x5D_` family. See "The receiver's remote" (section
11) for how phonkyo acts on them.

This is the more interesting half: it means the receiver's own remote can
drive playback on the Pi, if phonkyo listens for these and maps them onto
whatever is currently playing.

### Codes that are NOT available on a TX-8020 (exhaustively verified)

Do not spend time re-deriving these. Swept on real hardware:

- **All 256 families as `0xNN0`** (select input) -- 256 codes
- **All 256 families as `0xNNF`** (power on + select) -- 256 codes
- **Every command nibble `1`-`E` across all 256 families** -- 3,570 codes

**4,082 of the 4,096-code space.** The 14 excluded are the `0x42_` service
family (see the warning below). Results:

| Wanted | Found |
|---|---|
| TV input select | **no** -- no code selects TV in either form |
| Volume up/down | **no** -- `0x172/3` and `0x1A2/3` both inert |
| Mute | **no** |
| Input cycle/next | **no** |

This is now **two independent exhaustive sweeps** in agreement: ours, and the
developer whose published TX-8020 codes we started from, who brute-forced the
same space and found only those four inputs plus the dimmer family. TV is not
undiscovered -- it does not exist.

Only four inputs respond to select codes: CD, TAPE, BD/DVD, DOCK -- exactly
the four an RI-capable Onkyo *source device* plugs into. RI is a coordination
bus between the receiver and its source equipment; a TV has no RI connector
and nothing to coordinate, so Onkyo appears never to have assigned it a code.
No published table for any model lists one either.

### Sweep method, if this ever needs repeating

Watching a display for an hour does not work. Instead, play continuous audio
from the DAC with DOCK selected and *listen*: any code that changes the input
cuts the sound, which is far more noticeable than a display change and leaves
the operator free to do something else. Re-select DOCK every 32 codes so the
audio resumes and the operator can localise a hit to a 32-code window.

Caveat: mute and power-off cut the audio identically, so a dropout is a lead,
not an answer -- each one needs a follow-up look at the display.

Practical consequence: TV selection is not automatable over RI. Use the
receiver's own remote. This does not affect phonkyo's use case, which needs
`0x17F` (power on + select DOCK) and nothing else.

### DANGER: the 0x42_ family is service mode

`0x42_` is the factory **service/diagnostic** interface, not a normal command
family -- sweeping it put the receiver into a test mode displaying
`Test 1-00` ... `Test-04-00`. `0x420` (power off) lives here, which is
misleading: the rest of the family is not safe to probe. If it is entered
accidentally, power-cycle the receiver at the wall.

Any code-discovery tooling shipped to users must exclude `0x42_` except for
the known-good `0x420`.

### What the receiver does *not* emit

Input selection and volume changes produce nothing on the bus (verified with
repeated 30 s captures while pressing them). RI is largely a downstream bus --
the receiver commands attached sources, rather than broadcasting its own
state. Sniffing cannot discover volume or input codes; those have to come from
a code table or a sweep.

Volume was tested and **did not work** with either `0x172`/`0x173` (DOCK-family
offset) or the documented `0x1A2`/`0x1A3` (Video-family). It may not be
controllable from the dock side on this model.

The `...F` suffix means "power on and select this input"; `...0` selects only.
Published tables disagree about which family is DOCK — `0x1AF` is a different
input and does nothing useful here. Trust `0x17F`.

Each command is sent **3x** with a **50 ms idle gap** between frames; RI has no
acknowledgement, so repetition is how reliability is achieved.

## Verified end state

```
nqptp            enabled active
shairport-sync   enabled active   :7000     AirPlay 2
raspotify        enabled active   :46651    Spotify Connect
plexamp          enabled active   :32500    Plexamp
avahi-daemon     enabled active
card 0: sndrpihifiberry - snd_rpi_hifiberry_dac
```

mDNS advertises `2CCF…@phonkyo` (_raop), `phonkyo` (_airplay, vv=2) and
`raspotify (phonkyo)` (_spotify-connect). No service holds the ALSA device
while idle, so the three players coexist on the single card.

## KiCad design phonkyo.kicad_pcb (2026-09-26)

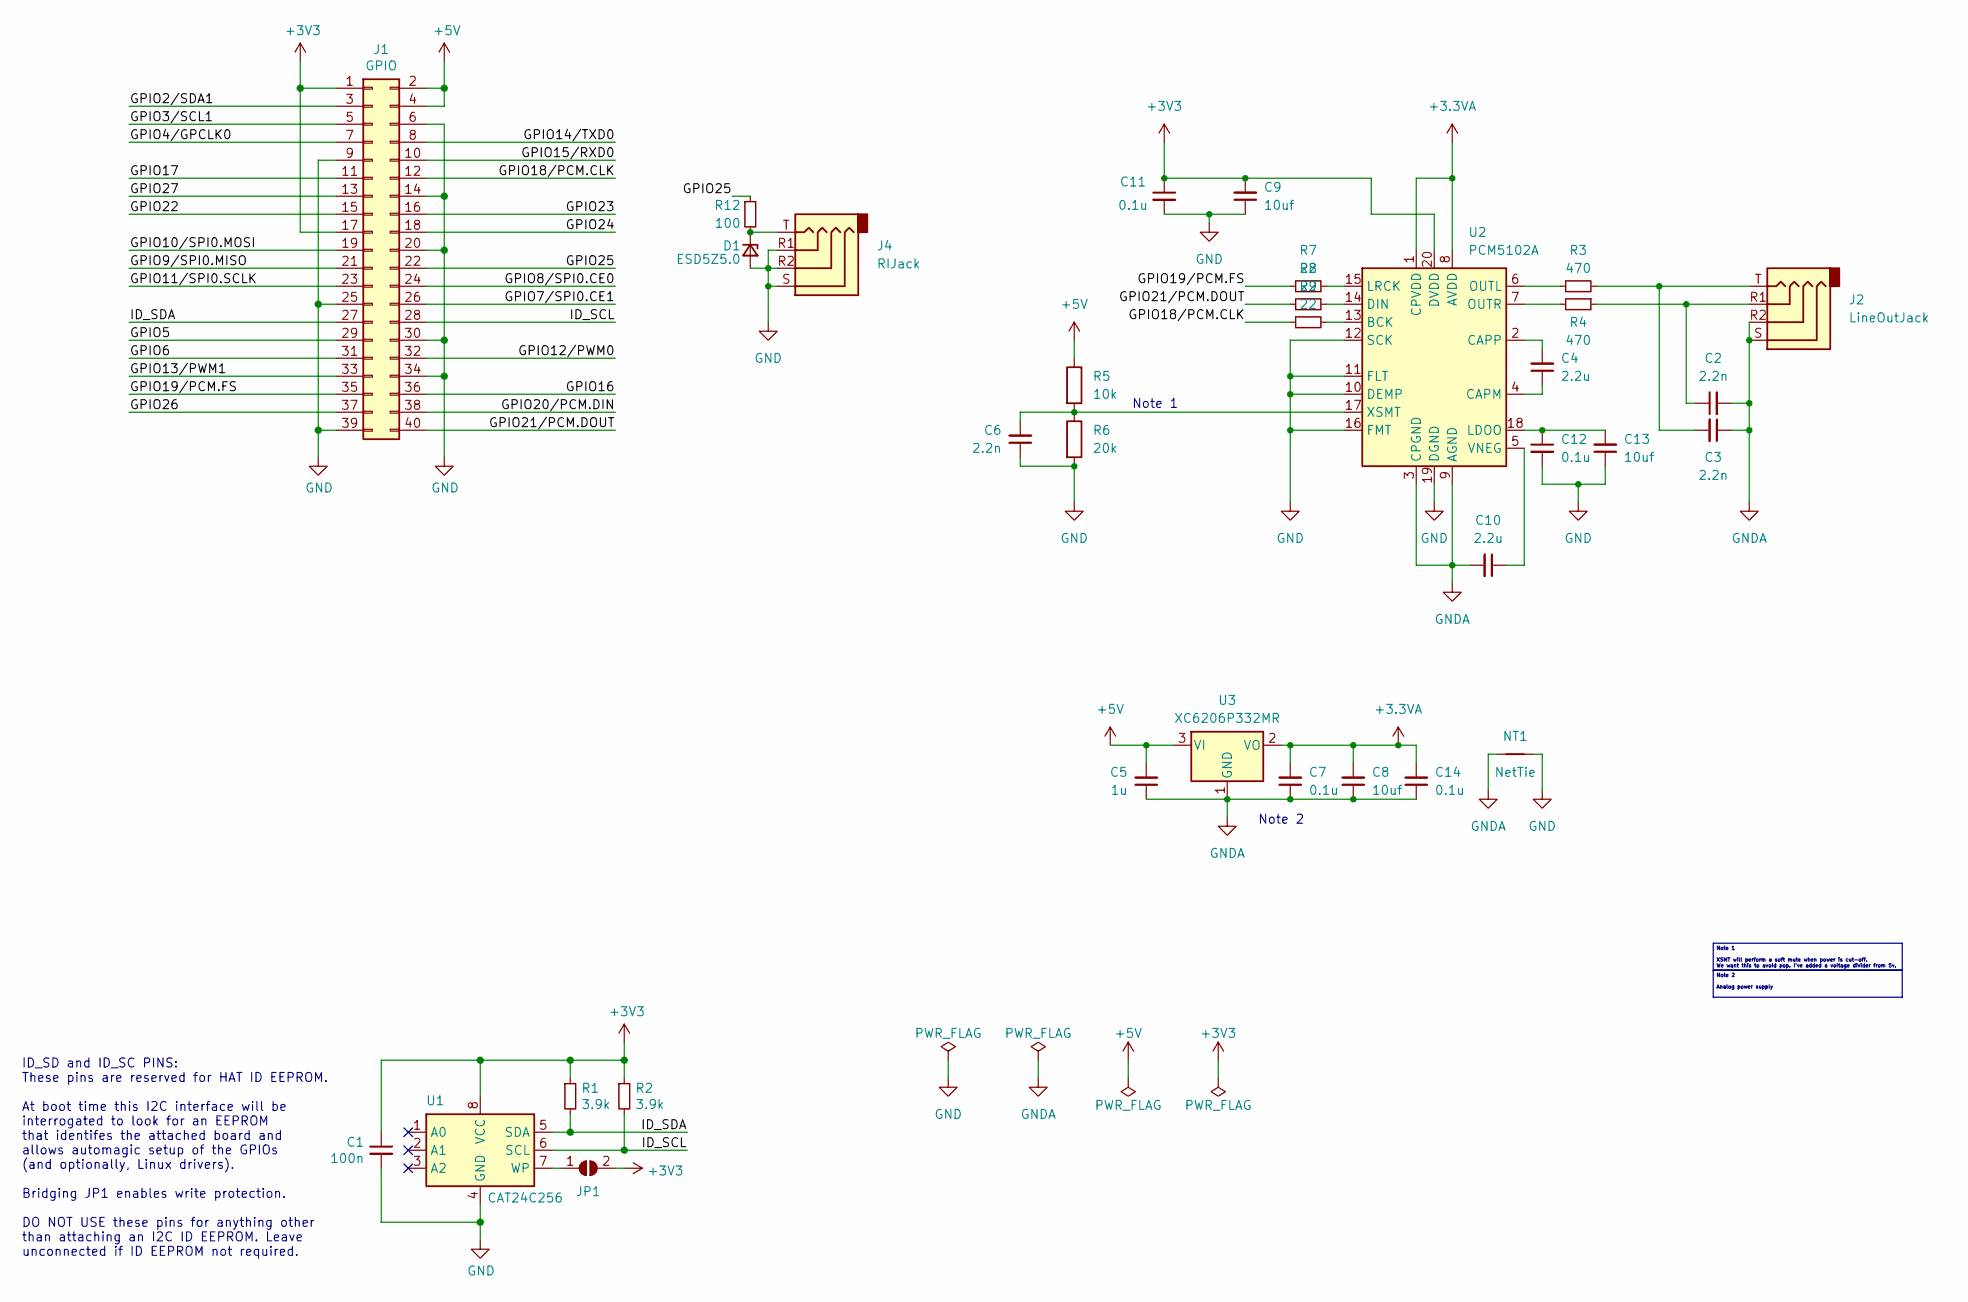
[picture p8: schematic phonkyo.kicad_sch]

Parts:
C1: 100n; C_0402_1005Metric; LCSC C1525
C2, C3, C6: 2.2n; C_0402_1005Metric; LCSC C385029
C4, C10: 2.2u; C_0402_1005Metric; LCSC C107369
C5: 1u; C_0603_1608Metric; LCSC C15849
C7: 0.1u; C_0603_1608Metric; LCSC C14663
C8, C9, C13: 10uf; C_0603_1608Metric; LCSC C19702
C11, C12, C14: 0.1u; C_0402_1005Metric; LCSC C1525
D1: ESD5Z5.0; D_SOD-523; LCSC C82044
J1: GPIO; PinSocket_2x20_P2.54mm_Vertical; LCSC C5124634
J2: LineOutJack; Jack_3.5mm_KoreanHropartsElec_PJ-320D-4A_Horizontal; LCSC C95562
J4: RIJack; Jack_3.5mm_KoreanHropartsElec_PJ-320D-4A_Horizontal; LCSC C95562
JP1: ID_WP; SolderJumper-2_P1.3mm_Open_Pad1.0x1.5mm
NT1: NetTie; NetTie-2_SMD_Pad0.5mm
R1, R2: 3.9k; R_0402_1005Metric; LCSC C131467
R3, R4: 470; R_0402_1005Metric; LCSC C25117
R5: 10k; R_0402_1005Metric; LCSC C25744
R6: 20k; R_0402_1005Metric; LCSC C25765
R7, R8, R9: 22; R_0402_1005Metric; LCSC C25092
R12: 100; R_0402_1005Metric; LCSC C25076
U1: CAT24C256; TSSOP-8_4.4x3mm_P0.65mm; LCSC C146734
U2: PCM5102A; TSSOP-20_4.4x6.5mm_P0.65mm; LCSC C107671
U3: XC6206P332MR; SOT-23-3; LCSC C5446

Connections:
+3.3VA: C7.2, C8.2, C14.2, U2.1 (CPVDD), U2.8 (AVDD), U3.2 (VO)
+3V3: C1.1, C9.2, C11.1, J1.1, J1.17, JP1.2 (B), R1.1, R2.1, U1.8 (VCC), U2.20 (DVDD)
+5V: C5.2, J1.2, J1.4, R5.1, U3.3 (VI)
/GPIO2/SDA1: J1.3
/GPIO3/SCL1: J1.5
/GPIO4/GPCLK0: J1.7
/GPIO5: J1.29
/GPIO6: J1.31
/GPIO7/SPI0.CE1: J1.26
/GPIO8/SPI0.CE0: J1.24
/GPIO9/SPI0.MISO: J1.21
/GPIO10/SPI0.MOSI: J1.19
/GPIO11/SPI0.SCLK: J1.23
/GPIO12/PWM0: J1.32
/GPIO13/PWM1: J1.33
/GPIO14/TXD0: J1.8
/GPIO15/RXD0: J1.10
/GPIO16: J1.36
/GPIO17: J1.11
/GPIO18/PCM.CLK: J1.12, R9.1
/GPIO19/PCM.FS: J1.35, R7.1
/GPIO20/PCM.DIN: J1.38
/GPIO21/PCM.DOUT: J1.40, R8.1
/GPIO22: J1.15
/GPIO23: J1.16
/GPIO24: J1.18
/GPIO25: J1.22, R12.1
/GPIO26: J1.37
/GPIO27: J1.13
/ID_SCL: J1.28, R2.2, U1.6 (SCL)
/ID_SDA: J1.27, R1.2, U1.5 (SDA)
GND: C1.2, C6.1, C9.1, C11.2, C12.2, C13.1, D1.2 (A), J1.6, J1.9, J1.14, J1.20, J1.25, J1.30, J1.34, J1.39, J4.R1, J4.R2, J4.S, NT1.2, R6.2, U1.4 (GND), U2.10 (DEMP), U2.11 (FLT), U2.12 (SCK), U2.16 (FMT), U2.19 (DGND)
GNDA: C2.2, C3.1, C5.1, C7.1, C8.1, C10.2, C14.1, J2.R2, J2.S, NT1.1, U2.3 (CPGND), U2.9 (AGND), U3.1 (GND)
unnamed: C2.1, J2.R1, R4.1
unnamed: C3.2, J2.T, R3.2
unnamed: D1.1 (K), J4.T, R12.2
unnamed: JP1.1 (A), U1.7 (WP)
unnamed: R9.2, U2.13 (BCK)
unnamed: C4.1, U2.4 (CAPM)
unnamed: C4.2, U2.2 (CAPP)
unnamed: R8.2, U2.14 (DIN)
unnamed: C12.1, C13.2, U2.18 (LDOO)
unnamed: R7.2, U2.15 (LRCK)
unnamed: R3.1, U2.6 (OUTL)
unnamed: R4.2, U2.7 (OUTR)
unnamed: C10.1, U2.5 (VNEG)
unnamed: C6.2, R5.2, R6.1, U2.17 (XSMT)

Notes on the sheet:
Note 2
ID_SD and ID_SC PINS: These pins are reserved for HAT ID EEPROM. At boot time this I2C interface will be interrogated to look for an EEPROM that identifes the attached board and allows automagic setup of the GPIOs (and optionally, Linux drivers). Bridging JP1 enables write protection. DO NOT USE th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
Note 1
Note 1 XSMT will perform a soft mute when power is cut-off. We want this to avoid pop. I've added a voltage divider from 5v.
Note 2 Analog power supply

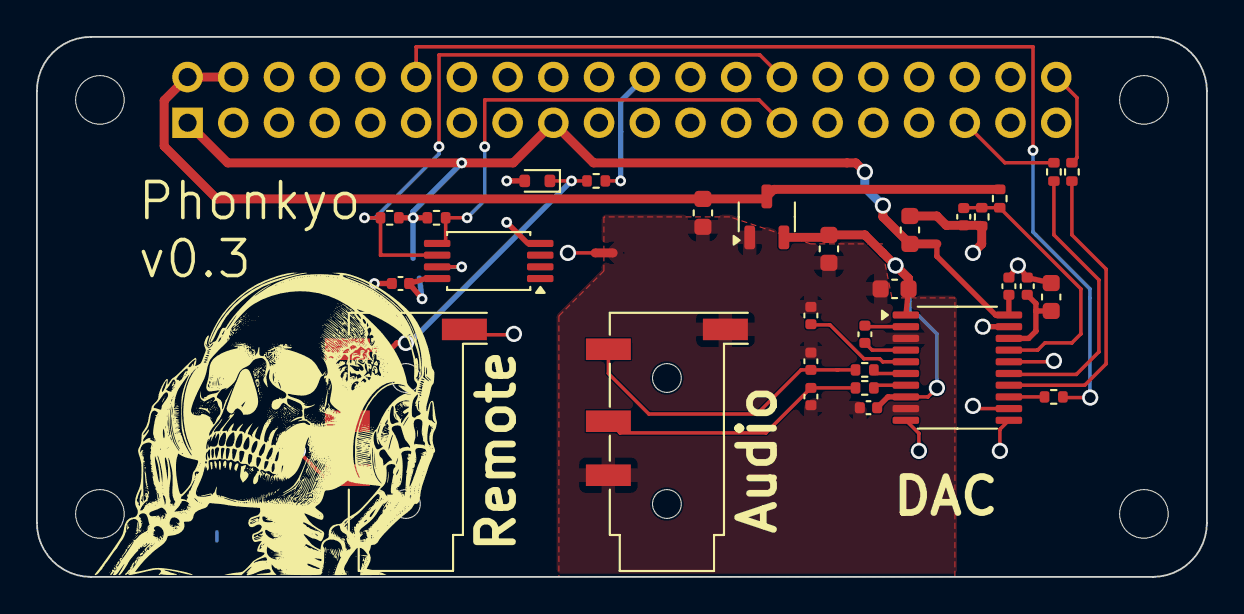
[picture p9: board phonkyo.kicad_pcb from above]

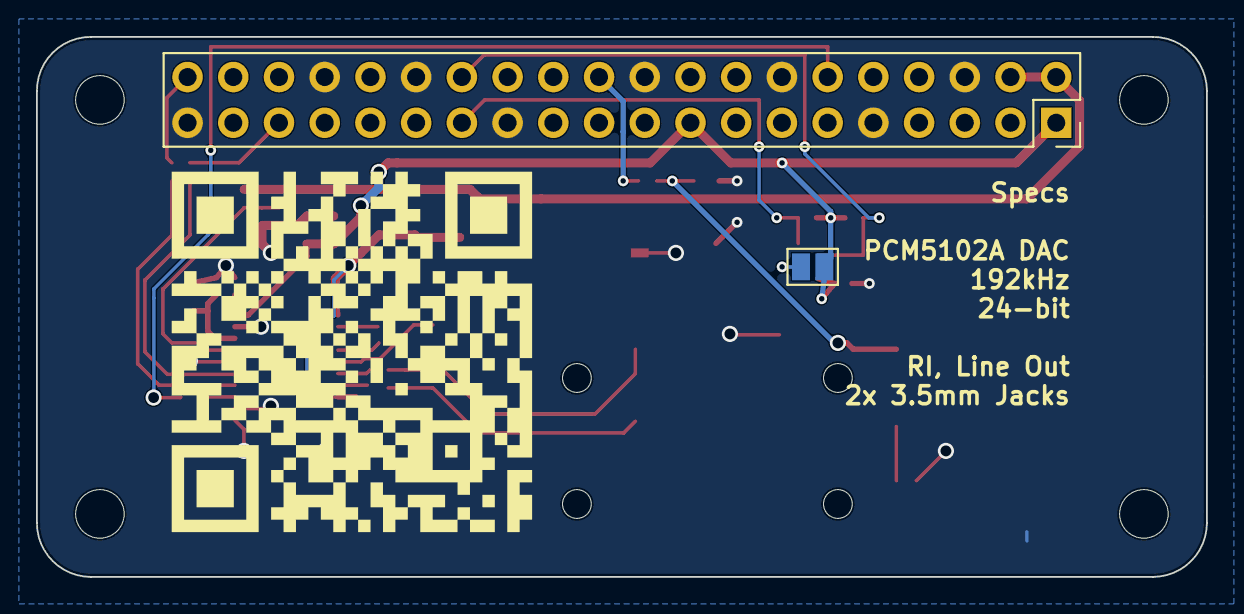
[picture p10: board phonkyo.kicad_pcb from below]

Board: 2 copper layers, 65.0 x 30.0 mm, 37 parts (2 on the bottom side), 25 nets.

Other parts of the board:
MH1, MH2, MH3, MH4: MountingHole_2.7mm_M2.5

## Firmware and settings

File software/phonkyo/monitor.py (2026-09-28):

"""Watch the DAC for playback and drive the amplifier over RI.

Turns the receiver on (and selects DOCK) when audio starts, and off again
after a quiet period, so the amp follows AirPlay/Spotify/Plexamp automatically.
It also listens for the receiver's transport buttons, which the receiver
forwards to the dock over RI, and passes them to Plexamp (see remote.py).

Detecting playback is subtler than it looks. The previous phonkyo build keyed
on `subdevices_avail` in /proc/asound -- i.e. "is the PCM device claimed". That
is wrong here: Plexamp opens the device at startup and holds it in PREPARED
state indefinitely while completely idle, which would switch the amp on at boot
and never let it off. We instead require state==RUNNING *and* hw_ptr to have
advanced since the last poll, which distinguishes real playback from a device
that is merely open, or open and stalled.
"""

from __future__ import annotations

import argparse
import logging
import signal
import sys
import time
from dataclasses import dataclass

from .remote import RILine, RemoteListener, RemoteRouter
from .ri import COMMANDS, RITransmitter, RealTimeUnavailable

LOG = logging.getLogger("phonkyo.monitor")

STATUS_PATH = "/proc/asound/card{card}/pcm{device}p/sub{sub}/status"


@dataclass
class PlaybackState:
    running: bool
    hw_ptr: int | None


class PlaybackDetector:
    def __init__(self, card: int = 0, device: int = 0, sub: int = 0):
        self.path = STATUS_PATH.format(card=card, device=device, sub=sub)
        self._last_ptr: int | None = None

    def _read(self) -> PlaybackState:
        try:
            with open(self.path) as fh:
                text = fh.read()
        except FileNotFoundError:
            return PlaybackState(False, None)
        if text.startswith("closed"):
            return PlaybackState(False, None)
        running = False
        hw_ptr = None
        for line in text.splitlines():
            if line.startswith("state:"):
                running = line.split(":", 1)[1].strip() == "RUNNING"
            elif line.startswith("hw_ptr"):
                try:
                    hw_ptr = int(line.split(":", 1)[1])
                except ValueError:
                    pass
        return PlaybackState(running, hw_ptr)

    def is_playing(self) -> bool:
        """True only if the stream is RUNNING and samples are actually moving."""
        state = self._read()
        if not state.running or state.hw_ptr is None:
            self._last_ptr = state.hw_ptr
            return False
        advanced = self._last_ptr is not None and state.hw_ptr > self._last_ptr
        # First observation of a RUNNING stream counts as playing; we cannot
        # yet know whether the pointer is moving, and a false positive here is
        # far cheaper than a delayed power-on.
        first_sight = self._last_ptr is None
        self._last_ptr = state.hw_ptr
        return advanced or first_sight


class AmpController:
    def __init__(self, gpio: int = 25, repeat: int = 3, dry_run: bool = False,
                 line: RILine | None = None):
        self.gpio = gpio
        self.repeat = repeat
        self.dry_run = dry_run
        # When the remote listener owns the RI line, transmit through it so the
        # GPIO is never claimed twice.
        self.line = line
        # Starts False deliberately: phonkyo only ever switches off an amp it
        # switched on. Otherwise turning the receiver on yourself for vinyl or
        # TV would have phonkyo silently kill it after the idle timeout.
        self.powered: bool = False

    def _send(self, name: str) -> None:
        code = COMMANDS[name]
        if self.dry_run:
            LOG.info("dry-run: would send %s (%#05x)", name, code)
            return
        try:
            if self.line is not None:
                errors = self.line.send(code, repeat=self.repeat)
            else:
                with RITransmitter(gpio=self.gpio) as tx:
                    errors = tx.send(code, repeat=self.repeat, verify=True)
            worst = max(abs(e) for e in errors)
            LOG.info("sent %s (%#05x) x%d, worst edge error %.1f us",
                     name, code, self.repeat, worst)
        except RealTimeUnavailable:
            LOG.error("no SCHED_FIFO: refusing to transmit, timing would be unreliable")
            raise

    def on(self) -> None:
        if self.powered is True:
            return
        LOG.info("playback started -> powering amp on, selecting DOCK")
        self._send("power_on_dock")
        self.powered = True

    def off(self) -> None:
        if not self.powered:
            return
        LOG.info("idle timeout reached -> powering amp off")
        self._send("power_off")
        self.powered = False


def run(poll_interval: float, idle_timeout: float, gpio: int, dry_run: bool,
        remote: str = "control") -> int:
    detector = PlaybackDetector()
    line = None
    if remote != "off":
        listener = RemoteListener(RemoteRouter(control=(remote == "control" and not dry_run)))
        line = RILine(listener.on_frame, gpio=gpio)
        LOG.info("listening for the receiver's transport buttons (%s mode)",
                 "log" if remote == "log" or dry_run else "control")
    amp = AmpController(gpio=gpio, dry_run=dry_run, line=line)

    stopping = False

    def _stop(signum, _frame):
        nonlocal stopping
        LOG.info("received signal %s, stopping", signum)
        stopping = True

    signal.signal(signal.SIGTERM, _stop)
    signal.signal(signal.SIGINT, _stop)

    LOG.info("watching %s (poll %.1fs, idle timeout %.0fs)",
             detector.path, poll_interval, idle_timeout)

    quiet_since: float | None = None
    while not stopping:
        playing = detector.is_playing()
        now = time.monotonic()

        if playing:
            quiet_since = None
            amp.on()
        else:
            if quiet_since is None:
                quiet_since = now
            elif now - quiet_since >= idle_timeout:
                amp.off()
                quiet_since = None  # do not re-send until playback resumes

        time.sleep(poll_interval)

    if line is not None:
        line.close()
    LOG.info("stopped")
    return 0


def main(argv: list[str] | None = None) -> int:
    ap = argparse.ArgumentParser(description=__doc__)
    ap.add_argument("--poll", type=float, default=2.0, help="seconds between checks")
    ap.add_argument("--idle-timeout", type=float, default=300.0,
                    help="seconds of silence before powering the amp off")
    ap.add_argument("--gpio", type=int, default=25)
    ap.add_argument("--dry-run", action="store_true",
                    help="log what would be sent without driving the line")
    ap.add_argument("--remote", choices=("control", "log", "off"), default="control",
                    help="act on the receiver's transport buttons, only log them, or ignore them")
    ap.add_argument("-v", "--verbose", action="store_true")
    args = ap.parse_args(argv)

    logging.basicConfig(
        level=logging.DEBUG if args.verbose else logging.INFO,
        format="%(levelname)s %(message)s",
        stream=sys.stdout,
    )
    return run(args.poll, args.idle_timeout, args.gpio, args.dry_run, args.remote)


if __name__ == "__main__":
    raise SystemExit(main())

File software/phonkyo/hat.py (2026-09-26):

"""Identify the phonkyo board from its HAT ID EEPROM.

When U1 is populated and programmed, the Pi firmware reads it at boot and
publishes the contents under /proc/device-tree/hat/. That gives software a
reliable answer to two questions a shipped product needs to ask:

  - is this actually running on phonkyo hardware, or has someone installed
    the software on a bare Pi and wondered why there is no sound?
  - which board revision is it, so behaviour can adapt without the user
    being asked

Everything degrades gracefully: on a board with no EEPROM (v0.2), or one
not yet programmed, detect() returns None and callers fall back to their current behaviour.
"""

from __future__ import annotations

import re
from dataclasses import dataclass
from pathlib import Path

HAT_DIR = Path("/proc/device-tree/hat")
VENDOR = "obcecado.com"
PRODUCT_ID = 0x0001  # phonkyo; other Obcecado boards use other ids


@dataclass(frozen=True)
class HatInfo:
    vendor: str
    product: str
    product_id: int
    product_ver: int
    uuid: str

    @property
    def is_phonkyo(self) -> bool:
        return self.vendor.lower() == VENDOR and self.product_id == PRODUCT_ID

    @property
    def revision(self) -> str:
        """product_ver 0x0003 -> 'v0.3'."""
        return f"v{self.product_ver // 10}.{self.product_ver % 10}"


def _read(name: str) -> str:
    # device-tree properties are NUL-terminated
    return (HAT_DIR / name).read_bytes().rstrip(b"\x00").decode("utf-8", "replace")


def _read_int(name: str) -> int:
    raw = _read(name).strip()
    return int(raw, 16) if raw.lower().startswith("0x") else int(raw or 0)


def detect() -> HatInfo | None:
    """Return the fitted HAT's identity, or None if no EEPROM is present."""
    if not HAT_DIR.is_dir():
        return None
    try:
        return HatInfo(
            vendor=_read("vendor"),
            product=_read("product"),
            product_id=_read_int("product_id"),
            product_ver=_read_int("product_ver"),
            uuid=_read("uuid"),
        )
    except (OSError, ValueError):
        return None


def alsa_card(name: str = "sndrpihifiberry") -> str | None:
    """Find the DAC by *name* rather than assuming it is card 0.

    Card numbering is not stable across machines -- a buyer who leaves HDMI
    audio enabled will have the DAC land on card 1, and a hardcoded "hw:0"
    then plays into the television. Referencing the card by name removes
    that whole class of support ticket.
    """
    try:
        cards = Path("/proc/asound/cards").read_text()
    except OSError:
        return None
    for line in cards.splitlines():
        # " 0 [sndrpihifiberry]: RPi-simple - ..."  -- the name field is
        # space-padded inside the brackets, so match to the bracket and strip
        m = re.match(r"\s*(\d+)\s+\[([^\]]+)\]", line)
        if m and m.group(2).strip() == name:
            return f"hw:CARD={name}"
    return None


if __name__ == "__main__":
    info = detect()
    if info is None:
        print("no HAT EEPROM detected (expected on v0.2, or an unprogrammed v0.3)")
    else:
        print(f"vendor      {info.vendor}")
        print(f"product     {info.product}")
        print(f"product_id  {info.product_id:#06x}")
        print(f"revision    {info.revision} (product_ver {info.product_ver:#06x})")
        print(f"uuid        {info.uuid}")
        print(f"is phonkyo  {info.is_phonkyo}")
    print(f"dac device  {alsa_card() or 'not found'}")

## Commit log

2024-10-06 finalize rev2 or v0.2
    [phonkyo.kicad_pcb, phonkyo.kicad_sch]
2024-10-06 finish BOM for v0.2 and submit to production
    [bom.csv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]
2024-10-29 add: revision 0.3
    [phonkyo.kicad_pcb, phonkyo.kicad_sch]
2026-09-22 add: phonkyo software stack for Raspberry Pi OS Trixie
    Brings up the v0.2 board's software on a fresh Trixie Lite install and
    documents the build so it can become a distributable installer.
    RI control (software/phonkyo/ri.py):
    - 12-bit Onkyo RI transmitter on GPIO25, plus a passive sniffer and
    frame decoder for learning codes off real hardware.
    - Uses lgpio rather than pigpio. pigpio is gone from Trixie, and its DMA
    timebase defaults to the PCM peripheral -- the same block the I2S DAC
    drives -- so it was never the right choice here.
    - SCHED_FIFO is mandatory, not an optimisation: measured worst-case edge
    error on a 1000us pulse is 2.5us with real-time priority against
    4005us witho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
    [monitor.py, ri.py]
2026-09-22 add: RI codes captured from a real receiver, alert-based sniffer
    Replaces the polling sniffer in ri.py with phonkyo.sniff, which
    timestamps edges via lgpio alerts in the kernel rather than from a
    Python loop. Captured pulses land within ~25us of nominal, which is what
    made the following measurements trustworthy.
    Protocol constants are now confirmed against hardware rather than
    inferred from community documentation. Measured off the receiver's own
    transmissions: header 2987us, header low 979us, bit high 1005us, bit-one
    low 1976us -- all within 2.5% of the assumed values.
    Captured the receiver->dock direction of the bus. With DOCK selected the
    receiver forwards its transport buttons to the a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
    [ri.py, sniff.py]
2026-09-22 docs: record exhaustive RI code search results for TX-8020
    Swept 608 codes on real hardware: all 256 families as 0xNN0 (select) and
    0xNNF (power on + select), plus every low nibble across the six families
    the receiver actually responds to.
    No TV input select exists, in either form. No volume, mute or input-cycle
    command either. Only four inputs respond -- CD, TAPE, BD/DVD, DOCK --
    which are precisely the four an RI-capable Onkyo source device plugs
    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
2026-09-23 docs: address the DAC by card name in shairport-sync config
    Changes the documented shairport-sync setting from output_device =
    "hw:0" to "hw:CARD=sndrpihifiberry", and applies the same change on the
    prototype. Card numbers are not stable across machines: with HDMI audio
    left enabled the DAC enumerates as card 1 and hw:0 plays into the TV.
    Verified on the Pi that ALSA resolves the named device and shairport-sync
    restarts cleanly with it. raspotify and Plexamp use the ALSA default and
    hardcode no card number, so nothing else needed changing.
2026-09-23 docs: add hardware review of the v0.3 design
    Review of the v0.3 schematic and layout, based on parsing the KiCad
    files directly. It records what the design does well: the analog/digital
    split runs through the DAC itself, the output filter is tight, the star
    ground is sound, and the outputs correctly have no DC-blocking caps.
    Eight findings are ranked by value per effort. The top three are the
    missing functional silkscreen (the identical, unlabelled jacks caused a
    real mix-up during bring-up), the I2S bit clock running 54.8 of its 56.4
    mm on B.Cu with no reference plane, and 100 nF decoupling placed 3.7 to
    5.6 mm from its pins. The review also covers the ~15 us XSMT time
    constant, the ground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
2026-09-23 chore: convert design to KiCad 10 format
    Upgrades the schematic and board with kicad-cli 10.0.6:
    phonkyo.kicad_sch 20231120 (8.0) -> 20260306 (10.0)
    phonkyo.kicad_pcb 20240108 (8.0) -> 20260206 (10.0)
    The files will no longer open in KiCad 8 or 9.
    The text diff is ~31k lines because KiCad re-serialises the whole file,
    so it cannot be reviewed by reading. The conversion was verified instead
    by exporting from KiCad 10 before and after and comparing the outputs:
    - Netlist: 25 components, 45 nets, 111 pin connections, identical.
    - Gerbers and drill: 28 of 30 files identical after stripping comments
    and dates. F_Silkscreen and Edge_Cuts differ in text but are
    geometrically identical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
    [phonkyo.kicad_pcb, phonkyo.kicad_sch]
2026-09-23 pcb: move C7 to sit directly at U2 pin 1 (CPVDD)
    C7 is the 100 nF decoupling cap on the PCM5102A's charge-pump supply,
    CPVDD (pin 1). Per the datasheet, pin 1 is CPVDD rather than AVDD. C7
    was at (146.0, 81.8), 3.7 mm from the pin and reached by a track that
    ran down to a via beside the chip. The datasheet asks for supply and
    charge-pump decoupling "as close as possible to the device".
    C7 now sits horizontally at (147.65, 84.0). Its +3.3VA pad is directly
    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
    [phonkyo.kicad_pcb]
2026-09-23 docs: withdraw the XSMT finding and correct the decoupling finding
    Rechecked the review against the PCM5102A datasheet. Two corrections:
    The XSMT recommendation was wrong. The +5V divider onto XSMT is TI's
    External Power Sense Undervoltage Protection Mode (datasheet section
    11.3, Fig. 39), which mutes the DAC as the upstream rail falls. The
    review advised feeding the divider from +3V3, which would defeat that
    mode. It also advised enlarging C6, which would delay the mute. The
    finding is replaced with a note to leave the circuit as designed,
    including its real limitation on a Pi.
    Decoupling: pin 1 is CPVDD, not AVDD, and AVDD (pin 8) turns out to
    have no local capacitor at all. That is adde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
2026-09-23 pcb: put C11 on DVDD pin 20 and shorten the LDOO route
    C11, the 100 nF decoupling cap on DVDD (pin 20), sat 6.0 mm of track
    from its pin. That track was a diagonal from (150, 80.7), because the
    area above the right column was taken by C12/C13 (the LDOO caps) and
    the LDOO route looped around pins 19 and 20 to reach pin 18.
    Re-laid out the right-hand fan-out:
    - C11 sits directly above pin 20. Track to the pin: 6.0 mm -> 1.1 mm.
    - C12 and C13 move beside C11. LDOO runs straight down beside the pins
    to pin 18, replacing the loop. C12 to pin 18: 9.0 mm -> 3.9 mm.
    - Pin 19 (DGND) previously ran right to a via in the middle of that
    area. It now goes under the chip body to a via between the pa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
    [phonkyo.kicad_pcb, phonkyo.kicad_sch]
2026-09-23 add: C14, 100 nF decoupling on DAC AVDD (pin 8)
    AVDD (U2 pin 8) had no local decoupling. It was fed from beside pin 1
    through a via and a B.Cu detour, about 9 mm from any capacitor. TI's
    reference layout decouples CPVDD (pin 1) and AVDD (pin 8) separately.
    C14 is a 100 nF 0402 at (146.2, 90.6), about 1.6 mm from pin 8. Its GNDA
    pad sits in the analog pour. In the schematic it is the third cap on the
    LDO output rails, beside C7 and C8, with its own junctions.
    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
    [phonkyo.kicad_pcb, phonkyo.kicad_sch]
2026-09-23 docs: correct the silkscreen finding and flag the plot directory
    The review said the board had no functional silkscreen and that the two
    jacks were unlabelled. That was wrong. Both v0.2 and v0.3 carry knockout
    labels: Remote by J4, Audio by J2, DAC, the board name, and a specs
    block on the back. The text extraction used for the review assumed a
    fixed field order in gr_text and missed them. The finding is replaced
    with a correction note.
    The same search turned up a real issue, which takes the top slot: the
    v0.3 plot settings still output to production/v0.2. Generating v0.3
    fabrication files would overwrite the v0.2 files that were actually
    manufactured.
2026-09-24 add: HAT ID EEPROM (CAT24C256) with pull-ups, decoupling and WP jumper
    Enables the previously DNP ID EEPROM circuit so the Pi can identify the
    board and load its overlay at boot:
    - U1 CAT24C256, TSSOP-8, in the strip above the 3.5 mm jacks
    - R1/R2 3.9k pull-ups on ID_SD/ID_SC (HAT spec value), 0402
    - C1 100 nF at VCC (pin 8), with its own GND via
    - JP1 solder jumper on the bottom side: open = WP floats low
    (writable, for flashing), bridged = WP tied to +3V3 (protected)
    Routing is by hand. Both ID lines stay on F.Cu from the header: ID_SC
    along the board edge above the header, ID_SD between the header rows.
    B.Cu is used only for short vertical hops under the +3V3/+5V rails,
    plus a +3V3 ho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
    [phonkyo.kicad_pcb, phonkyo.kicad_sch]
2026-09-24 eeprom: ship the ID EEPROM on v0.3 (product_ver 0x0003)
    The ID EEPROM is now fitted on the v0.3 board (feat/v0.3-caps-eeprom), so
    the image identifies itself as v0.3 rather than v0.4. The statements that
    said v0.3 has no EEPROM are corrected in hat.py and the manifest. The
    hardware review is updated to mark the decoupling and EEPROM findings done,
    with the measured pad-to-pad distances.
    [hat.py]
2026-09-25 production: v0.3 fabrication and JLCPCB assembly files
    - Plot output now goes to production/v0.3 instead of overwriting v0.2.
    - Every fitted part has an LCSC field, in the schematic and on the PCB
    footprints, so the JLC BOM regenerates from the design. Basic parts are
    used wherever one fits. Extended picks: C0G for the 2.2 nF audio filter
    caps, 10 V for the 2.2 uF charge-pump caps, 3.9k 1% HAT pull-ups.
    - production/v0.3: Gerbers (with F.Paste for the stencil), Excellon
    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
    [phonkyo-B_Cu.gbl, phonkyo-B_Mask.gbs, phonkyo-B_Silkscreen.gbo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]
2026-09-25 production: ship v0.3 without J1; document header and flashing jig
    J1 is removed from the JLC BOM and CPL. Boards ship without the header,
    and customers solder it themselves. The README lists the LCSC header to
    buy separately and two ways to program the EEPROM on an unsoldered board:
    Pimoroni's Pogo-a-go-go, or a long-tail stacking header.
    [phonkyo-v0.3-bom-jlcpcb.csv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]
2026-09-25 design: replace R11 (0R) with a net tie between GND and GNDA
    The v0.2 prototype is quiet with the grounds joined, so the 0 ohm link no
    longer needs to be removable. NT1 is a KiCad net tie
    (NetTie-2_SMD_Pad0.5mm) in the same spot: a copper bridge with no part to
    place. It is excluded from the BOM and the placement file, and its pads
    are copper-only (no mask opening, no paste). Connectivity is unchanged:
    pin 1 on GNDA, pin 2 on GND.
    DRC with parity: 0 unconnected, 0 parity, library warnings only. ERC is
    unchanged. Production files are regenerated: 28 placed parts, J1 still
    left for hand soldering.
    [phonkyo-B_Cu.gbl, phonkyo-B_Mask.gbs, phonkyo-B_Silkscreen.gbo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]
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2026-09-25 sch: tidy wiring and junctions from the KiCad editor; date 2026-09-25
    Saved from the schematic editor. Connectivity is unchanged: the netlist
    matches the previous commit net for net, DRC parity against the PCB is 0,
    and ERC is unchanged.
    [phonkyo.kicad_sch]
2026-09-26 pcb: clip silkscreen at solder mask openings
    The skull logo's silkscreen covered 60-89% of J4's solder pads (T, R1,
    R2), and the plot settings did not subtract the mask from the
    silkscreen, so the silk Gerber printed ink on the RI jack pads. Enable
    subtractmaskfromsilk and regenerate the Gerbers. The logo is unchanged
    everywhere else.
    [phonkyo-B_Cu.gbl, phonkyo-B_Mask.gbs, phonkyo-B_Silkscreen.gbo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]
2026-09-26 eeprom: vendor "obcecado.com"; document ID pins; drop IR code
    - The EEPROM vendor is now "obcecado.com". hat.py identifies phonkyo by
    vendor plus product_id 0x0001, since the vendor is now the company
    rather than the product.
    - The EEPROM settings explain why GPIO0/1 (ID_SD/ID_SC) are not in the
    GPIO map: the HAT spec reserves them and eepmake rejects GPIOs below 2.
    Programming needs no map entry either: eepflash.sh brings up i2c-gpio
    on GPIO0/1 itself. The Makefile comment that said otherwise is fixed.
    - IR is not going to be used: remove software/phonkyo/ir.py and its
    manifest section, and renumber the later sections.
    Verified on the Pi: eepmake -v1 builds a 906-byte image (up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
    [hat.py]
2026-09-26 docs: bring the v0.3 hardware review up to date
    Every finding now has a status that reflects feat/v0.3-caps-eeprom, and a
    summary table tracks them:
    - Fixed: plot directory, decoupling (with re-measured pad-to-pad
    distances for all DAC capacitors), ID EEPROM (vendor obcecado.com,
    906-byte image, GPIO0/1 reserved), and a new finding 9 for the logo
    silkscreen that was printed over the J4 pads.
    - Decided: keep the split ground; R11 is now the net tie NT1, and a
    ferrite bead was rejected.
    - Open: BCK route, J4 ESD, output impedance, PWR_FLAGs.
    Corrections to stale facts: the pin names in the U2 split, the
    R3/R4-to-pin distance (0.8 mm pad to pad), and the GND via count (now
    12). The I2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
2026-09-26 pcb: move BCK to F.Cu; ESD clamp and series resistor on RI; PWR_FLAGs
    BCK (GPIO18) no longer runs 55 mm on B.Cu. Its top-edge run now sits on
    F.Cu above the header (y 70.55), over an unbroken B.Cu ground. It drops
    through the header gap at x 155.3 to one via, then takes the existing
    short B.Cu path to R9. BCK on B.Cu: 54.8 -> 15.1 mm. Total B.Cu track:
    102.5 -> 64.1 mm. The GND pour stays one piece and grows 1715 -> 1734 mm2.
    To make room, ID_SCL drops through the header gap east of pin 12, and the
    +3V3 hop to the EEPROM comes from a rail via at x 123.6. Their B.Cu
    segments stay parallel and do not cross.
    RI protection: GPIO25 is split where it passes between the +3V3 and +5V
    rails. J4's t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
    [phonkyo-B_Cu.gbl, phonkyo-B_Mask.gbs, phonkyo-B_Silkscreen.gbo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]
2026-09-26 docs: record BCK, RI protection and PWR_FLAG fixes; close finding 8
    The hardware review now marks finding 2 (BCK moved to F.Cu, with a
    before/after table) and finding 7 (R12 + D1 on the RI line) fixed. Finding
    8 is closed because J2 feeds an amplifier, and ERC is clean with the
    PWR_FLAGs added. The remaining list is down to measuring the RI
    pull-down, the ground topology if v0.3 shows noise, and an optional J2
    label. The manifest's RI note describes the v0.3 protection instead of
    asking for it.
2026-09-26 pcb: shift D1 so its silkscreen cathode bar clears the via
    The SOD-523 outline's cathode bar landed on the ring of the jack-side
    via, so the ink printed over the via and looked cramped. Move D1 and its
    GND via 0.3 mm left. The bar now sits in clear board. DRC is unchanged
    (0 unconnected, 0 parity). Production files are regenerated.
    [phonkyo-B_Cu.gbl, phonkyo-B_Mask.gbs, phonkyo-B_Silkscreen.gbo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]
2026-09-26 eeprom: rebuild per flash for unique UUIDs; verify by read-back; docs
    make flash wrote whatever phonkyo.eep was already built, and eepmake only
    generates a UUID when it builds. A batch flashed that way would share one
    UUID. flash now rebuilds the image every time, writes it with -y, reads
    the chip back, compares the bytes, and prints the board's UUID. Checked
    on the Pi: consecutive builds get different UUIDs, and the target
    expands as intended.
    Docs: the manifest lists v0.3 next to the verified v0.2, and gains the
    EEPROM identity and a step-by-step for programming a board (solder J1,
    JP1 open, make flash, bridge JP1). The UUID paragraph that said
    "at programming time" is corrected. The hard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
2026-09-26 production: J1 is hand-soldered in-house; drop the programming jigs
    The plan changed: headers are soldered and boards programmed before they
    ship, so the README no longer says customers solder J1, and the
    pogo-pin/stacking-header jig section is gone. The after-arrival steps
    are: solder J1, JP1 open, make flash (fresh UUID, read-back verify),
    bridge JP1.
2026-09-26 pcb: keep pours 0.25 mm from NPTH holes and 0.3 mm from the board edge
    A DRC with the project's ignored checks turned on and JLC-style limits
    found the GND and GNDA pours touching all 10 NPTH holes (4 mounting holes
    and the jack locating pegs, 0.0005 mm) and within 0.05 mm of the board
    edge. The project allowed 0 and 0.05 mm. Raise min_hole_clearance to
    0.25 mm and min_copper_edge_clearance to 0.3 mm, then refill. Only the
    pours change. The B.Cu GND pour is still one piece (1734 -> 1673 mm2).
    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
    [phonkyo-B_Cu.gbl, phonkyo-B_Mask.gbs, phonkyo-B_Silkscreen.gbo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]
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2026-09-26 docs: add finding 10 (pour clearance to NPTH holes and board edge), fixed
2026-09-26 3d: jack model, black solder mask, and product renders
    KiCad 10's library has no 3D model for the PJ-320D-4A jack, so J2 and J4
    were missing from renders. Add the manufacturer's model (from LCSC/EasyEDA,
    C95562) to 3dmodels/, referenced project-relative. It is rotated 270 deg
    and offset -3.15 mm to sit on KiCad's footprint, with the plug opening at
    the board edge.
    The stackup's solder mask colour is now black on both sides. This only
    affects the 3D view; choose black on the JLC order form.
    art/renders/: transparent PNGs for the sales site. An angled hero shot
    (high quality, with floor shadow), plus flat top and bottom views.
    [Jack_3.5mm_PJ-320D-4A.step, phonkyo.kicad_pcb]
2026-09-26 Prepare the repository for public release
    - LICENSE: CC BY-NC-SA 4.0. The README lists the third-party files it
    does not cover: the TI datasheet, the EasyEDA jack model and the KiCad
    library parts.
    - README: rewritten for newcomers, with renders, features, hardware
    summary, setup and ordering pointers, repository layout, and v0.3
    release notes. The original intro and release notes are kept.
    - Remove adc/example_pcb.webp (third-party image with an unknown
    licence; the Macsbug article is linked instead) and three Windows
    Zone.Identifier files.
    - Stop tracking phonkyo.kicad_prl (per-user KiCad view state).
    - .gitignore: fix a merged line that disabled the *.lck and __pycache__
    pat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
2026-09-28 installer: stop os-release overwriting the player name; silence the EEPROM probe
    Sourcing /etc/os-release set NAME to "Debian GNU/Linux", so the name
    question was skipped and the name failed validation. Read os-release in a
    subshell, and rename the script's own settings to PLAYER_NAME and
    PLAYER_LIST. Also move the 2>/dev/null around the EEPROM vendor read,
    since bash reports a failed input redirect before a later 2>/dev/null
    takes effect.
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2026-09-28 installer: match nqptp by its commit, not 1.2.8
    Correction to the previous commit: nqptp prints on stdout. A build from
    git reports its commit ("Version: c925f27."), not the release number, so
    the check now compares against the pinned commit.
